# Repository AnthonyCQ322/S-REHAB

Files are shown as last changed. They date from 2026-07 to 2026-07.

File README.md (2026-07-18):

<div align="center">

# S-REHAB




</div>

**Curso:** Instrumentación Biiomédica 

**Proyecto:** sistema wearable modular e inalámbrico creado para monitorear objetivamente la rehabilitación del hombro en pacientes con Síndrome de Pinzamiento Subacromial. 

---

## Sobre el Proyecto

Este repositorio está destinado a registrar el desarrollo de nuestro proyecto académico, es un sistema wearable médico, inalámbrico y de bajo costo diseñado para monitorizar de manera cuantitativa y objetiva la rehabilitación de pacientes jóvenes con Síndrome de Pinzamiento Subacromial. Cuenta con un módulo en el brazo que evalúa la cinemática del movimiento (ROM) con un sensor inercial (BNO055) y la fatiga del trapecio superior mediante sEMG (Myoware), junto con un módulo en el pecho que registra la frecuencia cardíaca mediante el sensor ECG (Max30001) del HealthyPi 5. El  proyecto utiliza Edge Computing que procesa la información localmente para activar un sistema de luces LED que alerta al paciente en tiempo real sobre los movimientos compensatorios o sobreesfuerzo. Finalmente, los datos se transmiten por Bluetooth a una interfaz en Unity 3D y a una plataforma web, ayudando al fisioterapeuta en las evaluaciones subjetivas tradicionales por un análisis clínico basado en datos precisos.

<p align="center">
  Imagen descriptiva del curso
</p>

---

## Integrantes (Grupo 4 S-REHAB)

<table align="center">
  <tr>
    <td align="center" width="33%">
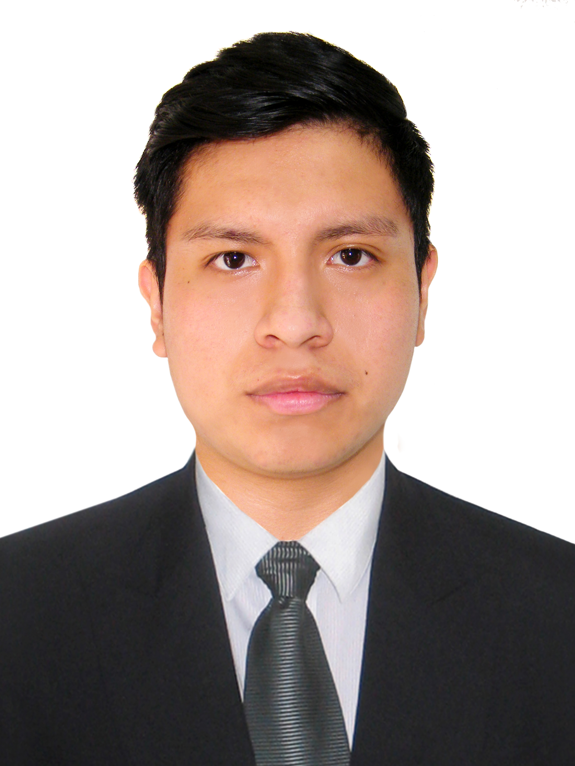
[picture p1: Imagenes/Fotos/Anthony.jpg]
Foto Integrante 1
      <br>
      <b>Anthony Frank Callupe Quispe</b><br>
      <i>"Estudiante de Ingeniería Biomédica apasionado por el análisis de datos médicos."</i><br><br>
      ✉️ <a href="anthony.callupe@upch.pe">anthony.callupe@upch.pe</a>
    </td>
    <td align="center" width="33%">
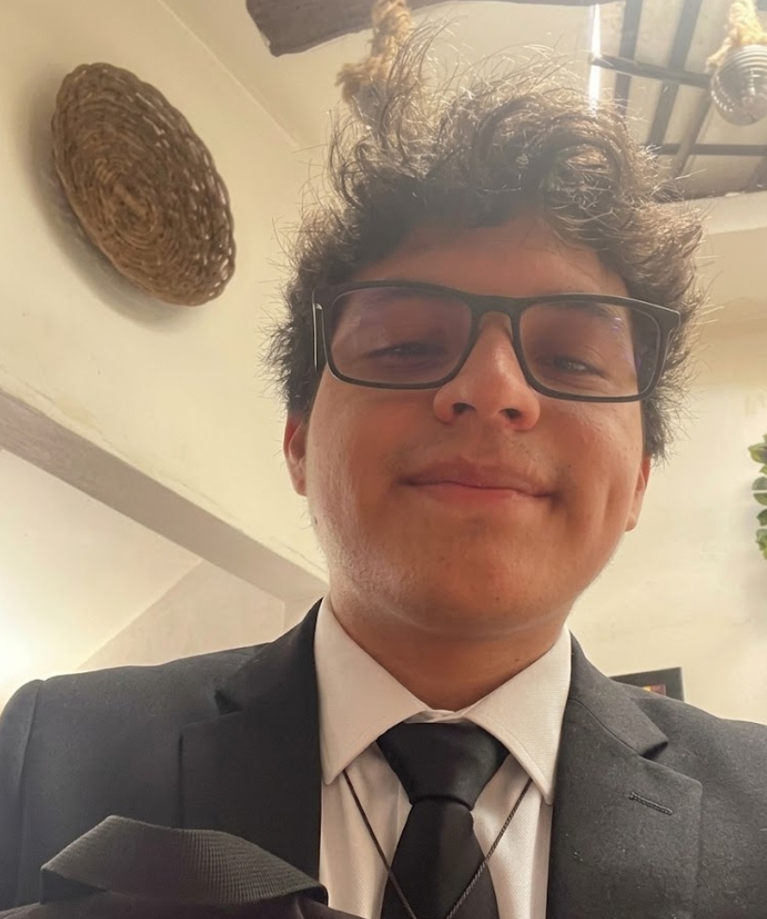
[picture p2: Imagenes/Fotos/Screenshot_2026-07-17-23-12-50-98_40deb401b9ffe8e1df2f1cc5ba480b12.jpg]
Foto Integrante 1
      <br>
      <b>André Vallejo Canchanya</b><br>
      <i>"Apasionado por el Machine Learning y el diagnóstico temprano de enfermedades."</i><br><br>
      ✉️ <a href="andre.vallejo@upch.pe">andre.vallejo@upch.pe</a>
    </td>
    <td align="center" width="33%">
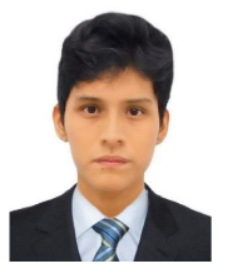
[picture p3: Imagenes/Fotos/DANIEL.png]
Foto Integrante 1
      <br>
      <b>Daniel Bagkdan Cárdenas Paniagua</b><br>
      <i>"Interesada en el procesamiento digital de bioseñales y la programación."</i><br><br>
      ✉️ <a href="daniel.cardenas@upch.pe">daniel.cardenas@upch.pe</a>
    </td>
  </tr>
  <tr>
    <td align="center" width="33%">
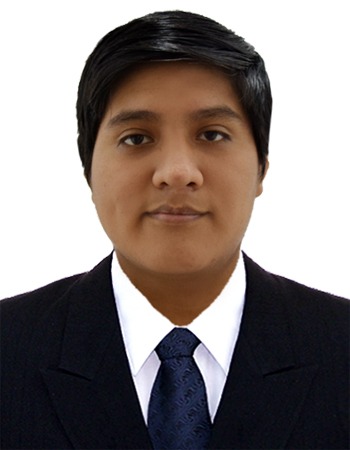
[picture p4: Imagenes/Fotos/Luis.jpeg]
Foto Integrante 1
      <br>
      <b>Luis Alejandro Luque Prado</b><br>
      <i>"Enfocado en el diseño de hardware médico e instrumentación electrónica."</i><br><br>
      ✉️ <a href="luis.luque@upch.pe">luis.luque@upch.pe</a>
    </td>
    <td align="center" width="33%">
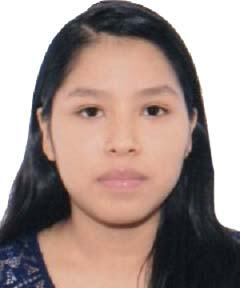
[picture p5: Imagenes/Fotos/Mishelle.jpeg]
Foto Integrante 1
      <br>
      <b>Mishelle Eloisa Llanos Guerrero</b><br>
      <i>"Dedicada a la investigación clínica y la validación de tecnologías de salud."</i><br><br>
      ✉️ <a href="mishelle.llanos@upch.pe">mishelle.llanos@upch.pe</a>
    </td>
    <td align="center" width="33%">
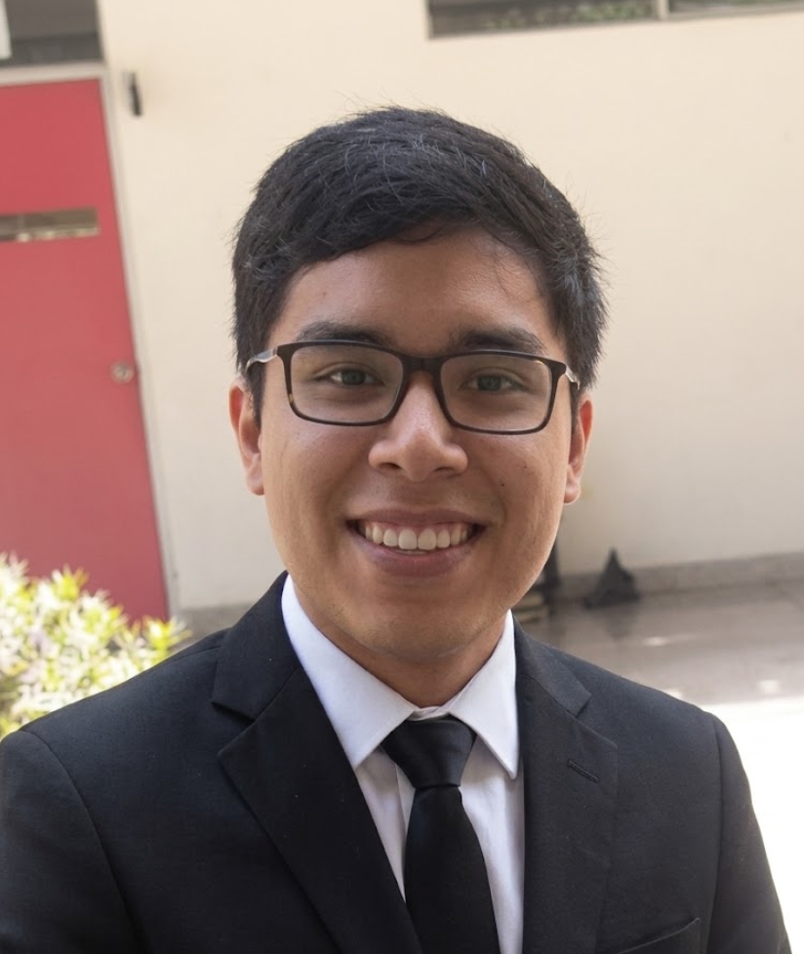
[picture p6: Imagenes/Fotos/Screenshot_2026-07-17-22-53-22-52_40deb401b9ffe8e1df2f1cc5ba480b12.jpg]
Foto Integrante 1
      <br>
      <b>André Alexis Palomino Mozo</b><br>
      <i>"Enfocado en el diseño de hardware médico e instrumentación electrónica."</i><br><br>
      ✉️ <a href="andre.palominoupch.pe">andre.palomino@upch.pe</a>
      </td>
  </tr>
</table>

---

## Docentes del Curso

El desarrollo de este proyecto y el aprendizaje a lo largo del semestre está guiado por nuestros docentes:

*  **HOYOS ALVITEZ MIGUEL ROGGER**

---

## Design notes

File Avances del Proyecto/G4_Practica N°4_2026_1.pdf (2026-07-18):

## UNIVERSIDAD PERUANA CAYETANO HEREDIA INGENIERÍA BIOMÉDICA

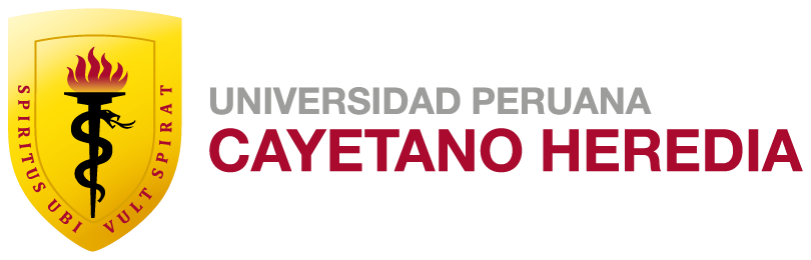
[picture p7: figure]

# PRÁCTICA DE INSTRUMENTACIÓN BIOMÉDICA

Solución final y componentes del prototipo.

# [Práctica N°4]

### GRUPO N° 4

### - Vallejo Canchanya, André - Luque Prado, Luis Alejandro - Cárdenas Paniagua ,Daniel Bagkdan - Callupe Quispe, Anthony Frank - Llanos Guerrero, Mishelle - Palomino Mozo, André Alexis

2026 -1

# Monitoreo Fisiológico y de Movimiento en rehabilitación de miembro superior

## 1. Objetivo

Consolidar la solución seleccionada en la Práctica 3 en una propuesta técnica final coherente e implementable, definiendo los componentes principales del prototipo basado en Healthy Pi 5, su arquitectura de integración, el flujo de uso real del sistema y las consideraciones básicas de usabilidad, seguridad y viabilidad para la siguiente etapa de desarrollo electrónico.

## 2. Integración final de resultados

### 2.1. Problema clínico-tecnológico reformulado

En la población de adultos jóvenes físicamente activos, el dolor de hombro presenta una alta prevalencia, siendo el Síndrome de Pinzamiento Subacromial (SIS) uno de los diagnósticos clínicos más frecuentes, representando hasta dos tercios de los casos de dolor de hombro [1]. En los procesos de rehabilitación actuales, no existe una forma objetiva y cuantitativa de monitorear la ejecución del movimiento. Esto genera una fuerte dependencia de evaluaciones clínicas subjetivas basadas en la observación visual y la estimación manual del fisioterapeuta [2].

Además, la falta de dispositivos accesibles limita la capacidad de cuantificar en tiempo real alteraciones del control escapulohumeral, como la disquinesia escapular y los patrones de activación muscular ineficientes [3]. Como consecuencia, la persistencia de estas compensaciones motoras puede reducir el espacio subacromial y contribuir a la perpetuación del dolor y la disfunción del hombro, afectando negativamente la recuperación funcional del manguito rotador [4].

En este contexto, se evidencia la necesidad de desarrollar herramientas accesibles que permitan un monitoreo objetivo y cuantitativo del control escapulohumeral durante la rehabilitación, facilitando la detección temprana de compensaciones motoras y la optimización de la técnica terapéutica.

### 2.2. Usuario objetivo

El sistema está dirigido a adultos jóvenes (18 a 30 años) con un perfil físicamente activo (deportistas recreativos o usuarios de entrenamiento de fuerza) que presentan diagnóstico de Síndrome de Pinzamiento Subacromial (SIS).

### 2.3. Contexto de uso

El dispositivo será utilizado en entornos intrahospitalarios, centros de terapia física o sesiones domiciliarias , bajo la supervisión de un fisioterapeuta encargado del proceso de rehabilitación.

### 2.4. Variable(s) fisiológica(s) seleccionada(s)

Primarias:

- Cinemática (vía IMU): Rango de movimiento (ROM), aceleración lineal y velocidad angular del miembro superior [5].

- Actividad Eléctrica Muscular Local (vía sEMG): Nivel de reclutamiento de unidades motoras (amplitud) y fatiga espectral (frecuencia mediana) de la musculatura del hombro [6].

Secundarias:

- Actividad Eléctrica del Corazón (ECG): Frecuencia Cardíaca (FC) [7].

### 2.5. Ruta técnica elegida

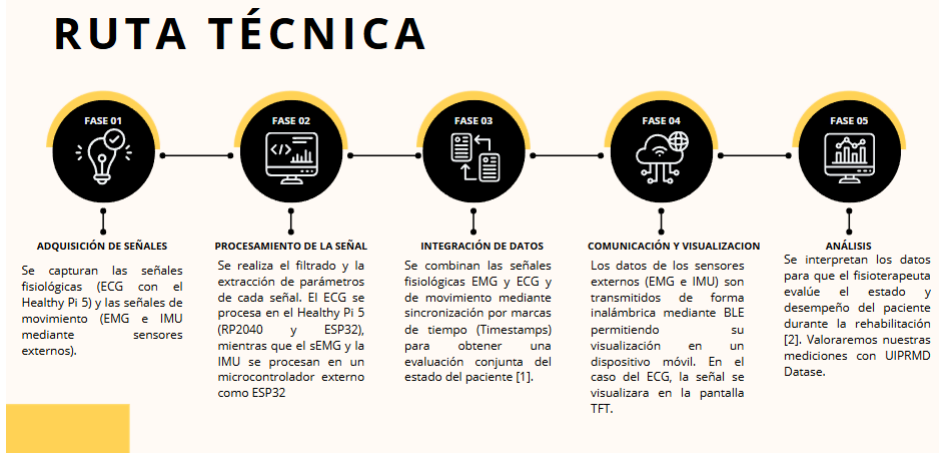
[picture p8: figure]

Fig. 1. Fases de la ruta técnica del sistema.

### 2.6. Solución escogida en la Práctica 3

La solución propuesta consiste en un sistema biomédico wearable, portátil e integrado para el monitoreo simultáneo de variables fisiológicas y cinemáticas durante la rehabilitación del miembro superior. El sistema adopta una arquitectura distribuida de dos módulos:

- Un módulo torácico basado en la plataforma Healthy Pi v5 para la adquisición de la señal ECG.
- Un módulo en el brazo basado en un microcontrolador ESP32 para la captura de señales locales de movimiento (IMU) y actividad muscular (sEMG).

Esta distribución permite desacoplar la adquisición de señales globales y locales, optimizando el procesamiento de datos y mejorando la ergonomía del sistema. La selección tecnológica responde a criterios de viabilidad económica, portabilidad y seguridad, priorizando una solución no invasiva que permite detectar compensaciones motoras sin restringir la movilidad del paciente durante la rehabilitación.

## 3. Solución final propuesta

### 3.1. Objetivo del sistema

Desarrollar un sistema biomédico wearable para el monitoreo en tiempo real durante la rehabilitación del miembro superior, enfocado en la detección de compensaciones motoras y el análisis del nivel de activación muscular, con el fin de mejorar la calidad de ejecución del ejercicio y apoyar la toma de decisiones clínicas.

### 3.2. Función principal

El sistema adquiere, procesa y analiza señales de movimiento (IMU) y actividad muscular (sEMG) para identificar:
- Compensaciones motoras: movimientos incorrectos o patrones de ejecución inadecuados durante el ejercicio.
- Nivel de activación muscular: como indicador del esfuerzo realizado y posible aparición de fatiga de manera indirecta.

Adicionalmente, el sistema registra la señal ECG y la frecuencia cardíaca (FC) como indicador fisiológico complementario.

### 3.3. Usuario final

- Usuario operante: Fisioterapeuta.
- Usuario paciente: Paciente en rehabilitación de miembro superior.

### 3.4. Contexto de uso real

El sistema está orientado a pacientes con disfunciones musculoesqueléticas del hombro en fase de rehabilitación funcional, particularmente aquellos con Síndrome de Pinzamiento Subacromial (SIS). Se utiliza en clínicas de rehabilitación o en sesiones domiciliarias supervisadas, donde el paciente ejecuta ejercicios terapéuticos mientras el fisioterapeuta monitorea la calidad del movimiento, la activación muscular y la evolución del desempeño.

### 3.5. Salida principal del sistema (visualización, alerta, registro o reporte)

### 3.5.1. Visualización en tiempo real

### 1. Visualización

- Indicador de calidad de movimiento (correcto / compensado), mostrado mediante la aplicación móvil.
- Nivel de activación muscular, representado mediante gráficos simples en función del tiempo.

### 2. Alertas de ejecución

- Notificación de compensaciones motoras para corrección de técnica.
- Indicación de niveles elevados y sostenidos de activación muscular que sugieren posible fatiga.

### 3. Registro de datos

- Señales de movimiento (IMU), sEMG y ECG almacenadas para análisis posterior.

### 4. Estado del sistema

- Indicadores LED que comunican el estado del dispositivo y la ejecución del movimiento de forma simple e intuitiva.

### 3.6. Valor agregado de la propuesta frente a las soluciones revisadas anteriormente

- Integración multimodal: combina análisis de movimiento (IMU) y actividad muscular (sEMG), permitiendo una evaluación más completa de la ejecución del ejercicio.

- Arquitectura distribuida sincronizada: el sistema opera mediante dos módulos independientes (brazo y pecho), cuya información es integrada en la aplicación móvil mediante sincronización por marcas de tiempo (timestamps), permitiendo correlacionar eventos de movimiento y activación muscular.
- Priorización del procesamiento: las variables críticas para la terapia (movimiento y activación muscular) se procesan en tiempo real, mientras que el análisis más complejo (como tendencias de fatiga) se realiza de forma diferida, mejorando la viabilidad del sistema y evitando la sobrecarga de información.

## 4. Componentes principales del prototipo

Módulo / Componente | Marca / Módulo | Función dentro del sistema | Variable o señal asociada | Característica técnica principal | Razón de selección
Plataforma base Healthy Pi 5 | ProtoCentra l (HealthyPi 5) | Procesamiento central de ECG y referencia temporal del sistema | Señal ECG, FC | Integra AFE clínico (MAX30001), microcontrolad or RP2040 y módulo inalámbrico ESP32-C3. | Centraliza la adquisición de la señal cardíaca, simplifica la integración del sistema y permite procesamiento local en tiempo real.
Sensor ECG | MAX30001 (Integrado en HealthyPi v5) | Adquisición y acondicionamient o de señales eléctricas cardíacas. | Señal ECG | AFE (Analog Front-End) de canal único, alta relación señal-ruido, protección contra desfibrilación. | Permite la adquisición de señal ECG con calidad adecuada para el monitoreo de la frecuencia cardíaca en tiempo real, sin requerir etapas adicionales de acondicionamiento analógico.

Sensor EMG | MyoWare Muscle Sensor (o módulo sEMG) | Monitoreo de nivel de activación muscular (indicador indirecto de fatiga | Señal EMG | Ancho de banda específico para músculos, salida analógica de envolvente (rectificada e integrada) o cruda. | Corrige el error del AD8232. Está diseñado específicamente para el espectro de frecuencias musculares, garantizando datos válidos.
Sensor IMU | BNO055 | Estimación de orientación del segmento corporal y cálculo de ángulos relativos | Ángulos de Euler, Cuaterniones y Gravedad lineal. | Sensor de 9 DoF con Digital Motion Processor (DMP) integrado para fusión de datos. | Entrega directamente datos de orientación procesados por hardware, reduciendo la necesidad de implementar algoritmos complejos de fusión (p. ej., filtros de Kalman) en el microcontrolador y facilitando la detección de patrones de movimiento en tiempo real.
Microcontrolad or secundario | ESP32 DevKit V1 | Digitalización de señales locales y transmisión inalámbrica de datos. | sEMG digitalizada y datos cinemáticos | Wi-Fi y Bluetooth Low Energy (BLE) integrados, ADC de 12 bits, doble núcleo. | Permite la arquitectura distribuida. Procesa y envía datos localmente en el brazo, evitando cables largos hacia el pecho.
Pantalla TFT (local) | TFT 3.5” (ST7797 o ILI9488) | Visualización en tiempo real de la estabilidad fisiológica sistémica. | Visualización de ECG y FC (BPM) | 3.5", resolución nativa, navegación por interruptor lateral. | Permite monitorear el esfuerzo cardíaco del paciente de forma directa sin dispositivos externos.

Módulo de visualización | Smartphone (App móvil) | Análisis biomecánico detallado y monitoreo de la técnica de rehabilitación. | Señal sEMG, Ángulos IMU, Trayectorias. | Interfaz gráfica avanzada con registro histórico vía BLE. | Facilita al especialista la evaluación de la compensación motora y fatiga sin saturar la pantalla pequeña del torso.
Sistema de alimentación | Batería Li-Po) + Módulo TP4056 | Gestión y suministro de energía autónoma regulada. | Voltaje DC (V) | Recargable, portátil y eficiente. | Garantiza la portabilidad (wearable) y cumple con el principio de seguridad eléctrica (aislado de la red comercial).
Módulo de comunicación | ESP32C3 RISC-V | Enlace inalámbrico (BLE) entre nodos y dispositivos receptor. | Paquetes de datos digitales (BLE) | Protocolo Bluetooth Low Energy 4.2 o 5.0. | Minimiza el consumo de batería, elimina el riesgo de enredo de cables y ofrece ancho de banda suficiente.
Electrodos | 3M Red Dot (Ag/AgCl) para sEMG y ECG. Pre-gelificad os, de baja impedancia | Transducción de potenciales bioeléctricos de la piel al sistema. | Potenciales bioeléctricos (mV) | Gel conductor sólido, desechables, alta adhesión, estándar ISO 10993. | Garantizan baja impedancia, reducen artefactos por movimiento y aseguran la higiene entre distintos pacientes.
Actuadores | Indicadores LED (verde/amari llo/rojo) | Generación de retroalimentación inmediata sobre la técnica de ejecución. | Señal digital | Bajo consumo (3V – 5V) y alta visibilidad | Permite diferenciar claramente entre estado del sistema y feedback de ejecución sin generar confusión clínica: verde indica funcionamiento correcto o ejecución adecuada, amarillo señala compensación motora (requiere corrección), y azul

nivel de activación
sostenida | que
sugiere | posible
fatiga

Tabla 1. Componentes del prototipo. Resumen de los módulos principales del sistema, sus funciones, variables asociadas y criterios técnicos de selección.

4. 1. Justificación técnica más detallada

### 4.1.1. AFE Bioeléctrico: MAX30001 (Integrado en HealthyPi v5)

El MAX30001 es un front-end analógico de biopotenciales diseñado para aplicaciones médicas portátiles, optimizado para la adquisición de señales ECG con calidad clínica y bajo consumo energético. Estudios comparativos muestran que la frecuencia cardíaca obtenida a partir de señales indirectas (como acelerómetros) presenta alta correlación (>0.99) con ECG clínico, confirmando que el ECG sigue siendo el estándar de referencia para mediciones cardiovasculares [8]. En este contexto, el uso del MAX30001, diseñado para ECG de grado clínico, garantiza una medición precisa y confiable de FC, validando su aplicación en monitoreo wearable sin comprometer la calidad diagnóstica.

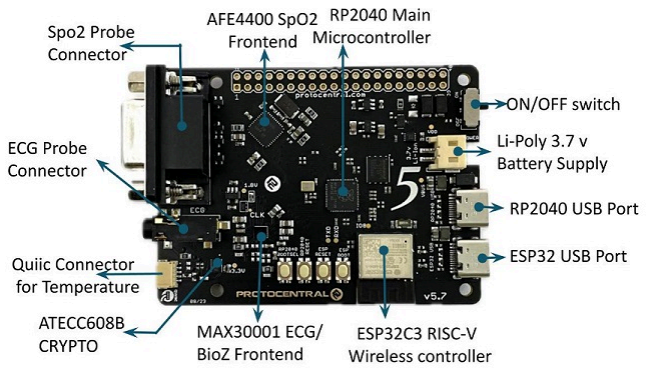
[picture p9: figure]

Fig. 2. Módulo AFE bioeléctrico basado en el MAX30001 integrado en la plataforma Healthy Pi 5.

Documentación técnica: Front/End analógico (AFE) biopotencial y bioimpedancia MAX30001 (https://www.digikey.es/es/product-highlight/m/maxim-integrated/max30001-biopotential-and-bioimpedance-afe)

- Rango de medición: ECG hasta ~65 mVpp con tolerancia a offsets de ±650 mV. Evita saturación por movimiento o contacto deficiente
- Resolución: ADC de 18 bits que permite detectar variaciones finas en la señal.
- Tipo de señal: Señal bioeléctrica de baja amplitud con alta impedancia (>1 GΩ) y alto CMRR.
- Voltaje o alimentación: Opera entre 1.8V–3.3V con consumo bajo (~0.5 mA).
- Interfaz de comunicación: SPI
- Portabilidad: Diseñado para wearables con modos de bajo consumo y FIFO interno.
- Compatibilidad con Healthy Pi 5: Integrado directamente en la plataforma. Elimina la necesidad de diseño analógico externo.
- Facilidad de implementación: Repositorio libre en GitHub y librerías disponibles en Protocentral Healthy Pi 5.
- Disponibilidad o costo aproximado: Costo aproximado de 10–16 € por chip

### 4.1.2. Sensor sEMG: MyoWare Muscle Sensor

El sensor MyoWare 2.0 permite la adquisición de señales electromiográficas superficiales (sEMG), utilizadas clínicamente para analizar la activación muscular y la coordinación motora. La electromiografía es una técnica ampliamente validada para evaluar patrones de contracción y fatiga muscular, proporcionando información sobre la intensidad y temporización del reclutamiento muscular en tiempo real [9]. En este contexto, el uso del MyoWare permite integrar mediciones musculares funcionales en un sistema wearable, complementando el análisis fisiológico con información biomecánica relevante para la rehabilitación de miembros superiores.

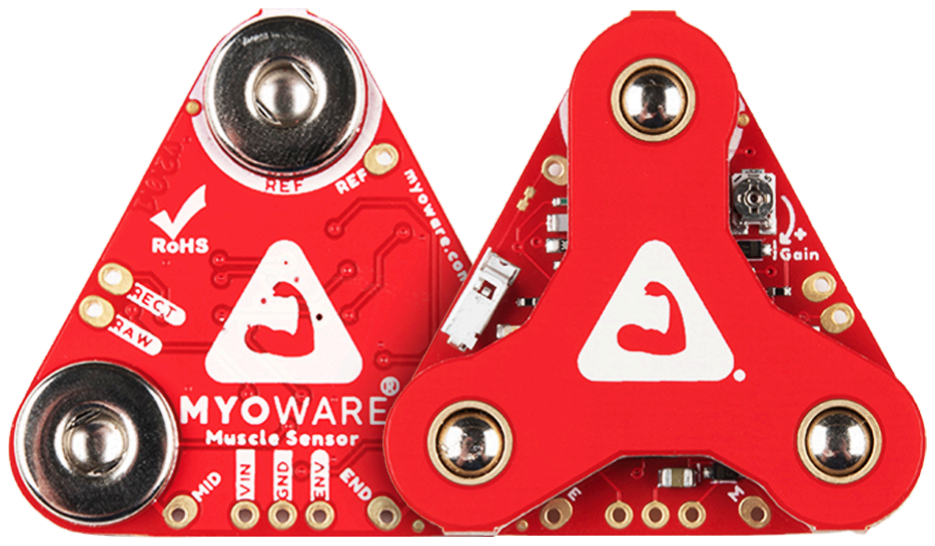
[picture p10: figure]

Fig. 3. Sensor de electromiografía superficial MyoWare 2.0 Muscle Sensor empleado para la medición de la actividad muscular (sEMG).

Especificaciones tecnica: Sensor EMG MyoWare 2.0, (https://naylampmechatronics.com/biomedico/1263-sensor-emg-myoware-20.html) otra versión (MyoWare™ (https://cdn.sparkfun.com/datasheets/Sensors/Biometric/MyowareUserManualAT-04-001.pdf) )

- Rango de medición: Señales EMG de baja amplitud (≈0–10 mV) amplificadas con ganancia ≈200. Salida adaptada a 0–Vcc para fácil adquisición.
- Resolución: Dependiente del ADC (ej. 12 bits en ESP32), suficiente para diferenciar niveles de activación muscular.
- Tipo de señal: Señal analógica con salidas RAW, rectificada y envolvente. Permite análisis en tiempo real sin procesamiento complejo.
- Voltaje o alimentación: Opera entre 2.27V–5.47V (típico 3.3V–5V). Compatible con sistemas embebidos portátiles.
- Interfaz de comunicación: Salida analógica directa hacia ADC. No requiere protocolos digitales adicionales.
- Portabilidad: Diseño compacto con sistema snap y electrodos integrados. Reduce cableado y facilita uso wearable.
- Compatibilidad con Healthy Pi 5: Requiere adquisición mediante microcontrolador externo (ESP32). Se integra vía arquitectura distribuida.
- Facilidad de implementación: Incluye filtrado (20–500 Hz), rectificación y ganancia ajustable. Evita diseñar acondicionamiento analógico.
- Disponibilidad o costo aproximado: Costo aproximado de S/ 370 en Perú. Disponible en proveedores locales.

### 3. Unidad de Medición Inercial (IMU): BNO055

El BNO055 es un sensor inercial de 9 grados de libertad ampliamente utilizado en aplicaciones biomédicas y de movimiento para estimar orientación corporal. La medición de aceleración, velocidad angular y campo magnético permite caracterizar la cinemática del movimiento humano, siendo clave en análisis biomecánico y rehabilitación [10]. Su integración de fusión de sensores en hardware permite obtener directamente orientación absoluta, facilitando el monitoreo preciso de la técnica del paciente en entornos wearables.

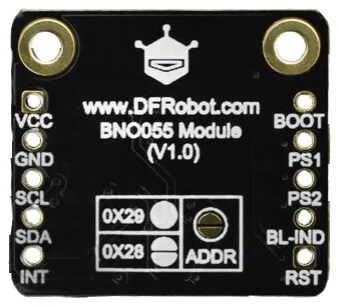
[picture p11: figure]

Fig. 4. Unidad de medición inercial BNO055 utilizada para la estimación de orientación y movimiento corporal mediante fusión de sensores.

Descripción técnica: BNO055 (https://mtlab.pe/producto/bno055-modulo-sensor-de-9-ejes-fermion-dfrobot/)

- Rango de medición: Acelerómetro ±2–16g, giroscopio ±125–2000 °/s, magnetómetro hasta ±1300 µT. Permite capturar movimientos humanos completos.
- Resolución: Acelerómetro de 14 bits y giroscopio de 16 bits. Proporciona alta precisión en la estimación de movimiento.
- Tipo de señal: Datos digitales procesados (cuaterniones, ángulos de Euler). Reduce la necesidad de procesamiento externo.
- Voltaje o alimentación: Opera entre 3.3V–5.5V. Compatible con sistemas embebidos portátiles.
- Interfaz de comunicación: I2C (principal) o SPI. Facilita integración con microcontroladores.
- Portabilidad: Tamaño compacto (~19x21 mm) y bajo consumo. Adecuado para dispositivos wearables.
- Compatibilidad con Healthy Pi 5: Integrable mediante I2C con MCU auxiliar (ESP32). Compatible con arquitectura distribuida.
- Facilidad de implementación: Incluye microcontrolador interno para sensor fusion. Elimina necesidad de filtros complejos (ej. Kalman).
- Disponibilidad o costo aproximado: Costo aproximado de $17–18 USD. Disponible en múltiples proveedores.

## 5. Diagrama de integración del sistema

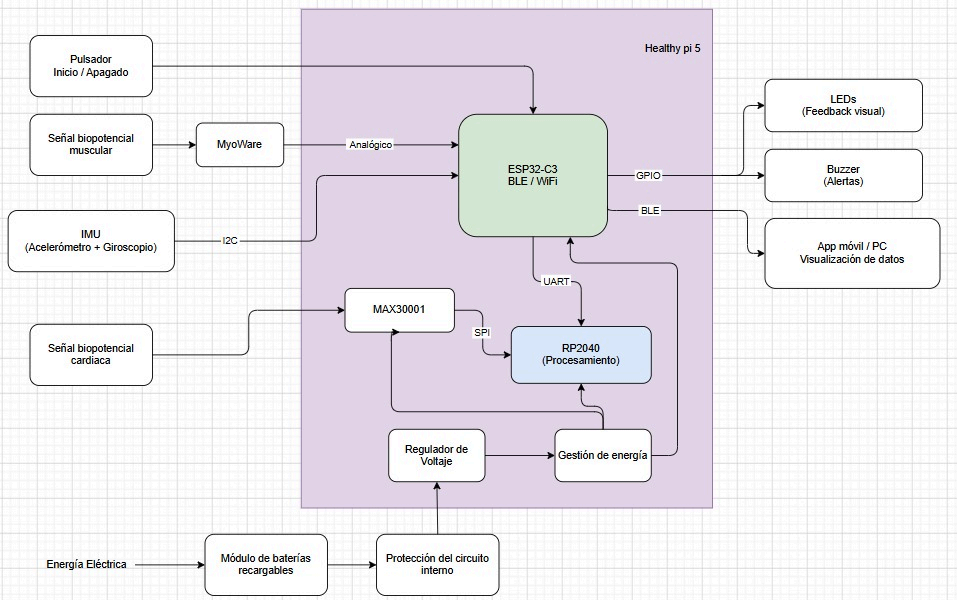
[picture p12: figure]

Fig. 5. Diagrama de bloques

## 6. Priorización de implementación

Elemento | Estado de Adquisición | Clasificación | Justificación
Healthy Pi 5 | Cubierto por el curso | Indispensable | Centraliza el procesamiento de ECG, gestión temporal y comunicación central.
Sensor ECG (Max30001) | Cubierto por el Healthy Pi 5 | Indispensable | Obtiene la frecuencia cardíaca (FC) de grado clínico.
Esp32 DevKit V1 | Integrar | Indispensable | Microcontrolador secundario necesario para el control del sensor IMU y el sensor sEMG en el brazo.
Sensor IMU (BNO055) | Adquirir | Indispensable | Variable primaria que entrega ángulos y velocidades procesados por hardware para detectar las compensaciones de movimiento.
Sensor sEMG (MyoWare) | Adquirir | Indispensable | Variable primaria que permite monitorear el nivel de activación y fatiga muscular.
Baterías Li-Po (3.7V) | Adquirir | Indispensable | Garantiza la seguridad eléctrica al estar aislada de la red eléctrica y la portabilidad.

Electrodos Ag/AgCl | Adquirir | Indispensable | Interfaz para la transducción de potenciales bioeléctricos.
Pantalla TFT 3.5" | Cubierto por el Healthy Pi 5 | Recomendable | Mostrará la monitorización del estado del sistema y FC de forma directa.
Indicadores LED | Adquirir | Recomendable | Brinda retroalimentación al paciente sobre la calidad técnica del movimiento.
Aplicativo | Referencial | Recomendable | Permite la visualización avanzada de gráficas y registro de datos del movimiento por el IMU.
Bandas elásticas y Case | Montaje | Opcional | Mejora la ergonomía y fijación.

Tabla 2. Elementos Indispensables, Recomendables y Opcionales para la elaboración del dispositivo final.

## 7. Escenario de uso real y tareas críticas

- Quién lo usa: Adultos jóvenes de 18 a 30 años físicamente activos con diagnóstico de Síndrome de Pinzamiento Subacromial donde el fisioterapeuta supervisa las sesiones.
- Dónde lo usa: Entornos intrahospitalarios, centros de terapia física.
- Cómo se coloca o inicia: El fisioterapeuta coloca el dispositivo al paciente, los electrodos sEMG se ubican en el trapecio superior y los de ECG en el tórax. El dispositivo se inicia mediante una conexión Bluetooth enviando información de los sensores hacia la app.
- Qué información observa o recibe:
- El paciente recibe retroalimentación mediante LEDs donde el color verde indica ejecución correcta, amarillo indica compensación motora y el Azul indica posible fatiga.
- El fisioterapeuta observa en la pantalla TFT la frecuencia cardíaca y la señal ECG mientras que en la app móvil visualiza las señales de EMG, ECG y la calidad de movimiento.
- Qué acción se espera del usuario o cuidador: El paciente debe realizar los movimientos indicados mientras que el fisioterapeuta analiza los datos y realiza correcciones de técnica gracias a la información obtenida.
- Cómo termina o se retira el sistema: Finalizando la sesión el fisioterapeuta retira el dispositivo del paciente y se desechan los electrodos Ag/AgCl para una correcta higiene.
Tarea crítica | Posible error de uso | Consecuencia o riesgo | Medida de diseño para mitigarlo
Colocación de electrodos sEMG | Ubicación fuera de la zona activa entre C7 y el acromion. | Baja calidad de la señal, captación de ruido. | Uso de cables tipo snap de longitud reducida con ruta anatómica fija para evitar tracciones.
Sincronización de módulos inalámbricos | Falla en una de las dos conexiones BLE simultáneas con la app. | Desfase temporal entre los datos de movimiento del IMU y la actividad muscular EMG. | La app centraliza la sincronización mediante el uso de timestamps para ambas señales.

Gestión de
alimentación de la
batería.

Uso del dispositivo
con un nivel de carga
insuficiente en alguno
de los módulos.

Apagado del sistema
y pérdida de
monitoreo durante la
sesión.

Uso de un LED de
estado del sistema para
confirmar el encendido
y funcionamiento
correcto.

Tabla 3. Tareas críticas y sus posibles errores y consecuencias del dispositivo

## 8. Consideraciones de usabilidad, seguridad y restricciones

El diseño del sistema wearable consideramos criterios de seguridad eléctrica, biocompatibilidad, ergonomía y usabilidad, los cuales condicionan directamente la arquitectura del sistema y las decisiones de diseño, con el fin de garantizar una medición confiable sin interferir con el patrón motor del paciente.

### 8.1. Normas y guías relevantes

El desarrollo del sistema se fundamenta en estándares internacionales que aseguran su seguridad y validez técnica:

- IEC 60601-1: Medical Electrical Equipment, General Requirements for Basic Safety and Essential Performance [11].
Establece los requisitos de seguridad eléctrica para equipos médicos. Su aplicación es crítica debido al uso simultáneo de dos módulos electrónicos con electrodos en contacto con el paciente, regulando las corrientes de fuga en partes aplicadas tipo BF y condicionando la necesidad de aislamiento entre nodos .
- ISO 10993-1: Biological Evaluation of Medical Devices [12].
Define los lineamientos para la evaluación de biocompatibilidad de materiales en contacto con el cuerpo humano. Se aplica a los electrodos adhesivos tipo Ag/AgCl utilizados en ECG y sEMG, garantizando seguridad en contacto cutáneo.
- SENIAM: Surface Electromyography for the Non-Invasive Assessment of Muscles Proporciona recomendaciones para la colocación de electrodos sEMG. Para el trapecio superior, establece la ubicación de los electrodos activos entre C7 y el acromion, con separación aproximada de 20 mm y orientación paralela a las fibras musculares, y el electrodo de referencia en el acromion. Su aplicación asegura la reproducibilidad y calidad de la señal [13].

### 8.2. Restricciones de diseño derivadas del contexto de uso

- Seguridad eléctrica en presencia de múltiples puntos de contacto: El sistema utiliza dos módulos independientes (pecho y brazo), cada uno con electrodos conectados al paciente. Esto introduce la necesidad de evitar trayectorias de corriente entre nodos y garantizar aislamiento eléctrico durante la operación.
- No interferencia con el movimiento del hombro: El dispositivo se emplea durante ejercicios activos de rehabilitación, por lo que no debe restringir el rango de movimiento ni alterar el patrón motor, ya que esto afectaría directamente la validez de las mediciones cinemáticas y musculares.
- Sensibilidad de la señal EMG al movimiento: La señal sEMG es susceptible a artefactos por movimiento y variaciones en la impedancia de contacto, lo que exige estabilidad en la colocación de electrodos y control del cableado.

- Gestión de la información según el usuario: El sistema genera múltiples variables fisiológicas, por lo que se requiere evitar la sobrecarga de información durante la sesión, diferenciando la información mostrada al fisioterapeuta y al paciente.

### 8.4. Decisiones de diseño adoptadas

- Arquitectura distribuida con comunicación inalámbrica (BLE): Cada módulo (Módulo Principal: Healthy pi y Módulo Secundario: ESP32+IMU+Myoware) opera de manera independiente y transmite datos mediante Bluetooth Low Energy (BLE) hacia una aplicación central. Esto permite eliminar conexiones físicas entre módulos durante el uso, reduciendo riesgos eléctricos y mejorando la libertad de movimiento.
- Alimentación autónoma mediante baterías Li-Po: Cada módulo cuenta con una batería Li-Po de 3.7V permitiendo la operación aislada de la red eléctrica. La recarga se realiza fuera del contacto con el paciente, reduciendo riesgos conforme a IEC 60601-1.
- Colocación estandarizada de electrodos: Los electrodos sEMG se ubican en el trapecio superior siguiendo SENIAM, con el electrodo de referencia en el acromion para mejorar estabilidad mecánica y reducir ruido. Los electrodos ECG se colocan en el tórax según configuración estándar. En ambos casos se emplean electrodos Ag/AgCl desechables para asegurar biocompatibilidad y baja impedancia.
- Minimización y fijación del cableado: Se emplearán cables tipo snap de longitud reducida, fijados al cuerpo mediante material adhesivo y enrutados por la región superior del hombro hacia el módulo del brazo. El cableado se dispone adherido a la piel, siguiendo trayectorias anatómicas que minimizan el movimiento relativo, evitando tracción sobre los electrodos y reduciendo artefactos durante la ejecución de los ejercicios.
- Ubicación proximal de los módulos: El módulo del brazo (ESP32 + IMU + sEMG) se ubica en la región deltoidea, reduciendo la longitud del cableado y favoreciendo la integración con el movimiento. El módulo de ECG se fija en el pecho para minimizar la distancia con los electrodos. Ambos módulos se integran en bandas elásticas con bolsillo incorporado, facilitando su colocación, ajuste y limpieza entre sesiones.
- Diseño de interfaz centrado en el usuario: Durante la rehabilitación, el sistema muestra únicamente información crítica en tiempo real, distribuida en dos módulos para evitar la sobrecarga cognitiva.

Módulo principal: El módulo del brazo (ESP32 + IMU + sEMG) brinda retroalimentación mínima mediante:

- LED verde: ejecución correcta del movimiento.
- LED amarillo: detección de compensación motora (requiere corrección).
- LED azul: nivel elevado y sostenido de activación muscular que sugiere posible fatiga y recomienda pausa.

No se presentan métricas ni alertas complejas, para no interferir con la concentración del paciente.

Módulo secundario: El módulo del pecho (Healthy Pi + pantalla TFT) presenta información básica en una interfaz simplificada:

- Frecuencia cardíaca (BPM).
- Señal ECG en tiempo real.

En caso de ejecución incorrecta, el sistema envía una notificación en tiempo real al fisioterapeuta, junto con indicadores de calidad de movimiento y nivel de activación muscular. La aplicación muestra estos datos de forma simple en tiempo real y registra las señales (movimiento, sEMG y ECG) para su análisis posterior. La estimación de fatiga muscular se realiza fuera de la sesión para evitar sobrecarga de información durante la terapia.

## 9. Bibliografía

[1] B. Singh, N. Bakti, y A. Gulihar, “Current concepts in the diagnosis and treatment of shoulder impingement”, Indian J. Orthop., vol. 51, núm. 5, pp. 516–523, 2017.
[2] J. Adolf et al., “Evaluation of functional tests performance using a camera-based and machine learning approach”, PLoS One, vol. 18, núm. 11, p. e0288279, 2023.
[3] U. G. Longo et al., “Scapular Dyskinesis: From basic science to ultimate treatment”, Int. J. Environ. Res. Public Health, vol. 17, núm. 8, p. 2974, 2020.
[4] W. B. Kibler, P. M. Ludewig, P. W. McClure, L. A. Michener, K. Bak, y A. D. Sciascia, “Clinical implications of scapular dyskinesis in shoulder injury: the 2013 consensus statement from the ‘Scapular Summit’”, Br. J. Sports Med., vol. 47, núm. 14, pp. 877–885, 2013.
[5] A. Carnevale et al., “Wearable systems for shoulder kinematics assessment: a systematic review”, BMC Musculoskelet. Disord., vol. 20, núm. 1, p. 546, 2019.
[6] S. B. Rodrigues, L. P. de Faria, A. M. Monteiro, J. L. Lima, T. M. Barbosa, y J. A. Duarte, “EMG signal processing for the study of localized muscle fatigue-pilot study to explore the applicability of a novel method”, Int. J. Environ. Res. Public Health, vol. 19, núm. 20, p. 13270, 2022.
[7] F. Shaffer y J. P. Ginsberg, “An overview of heart rate variability metrics and norms”, Front. Public Health, vol. 5, p. 258, 2017.
[8] Payette, J., Vaussenat, F., & Cloutier, SG (2024). Medición de la frecuencia cardíaca mediante el acelerómetro triaxial integrado en un dispositivo de escritura digital comercial. Sensors , 24 (7), 2238. https://doi.org/10.3390/s24072238
[9] Bu D, Guo S, Li H. sEMG-Based Motion Recognition of Upper Limb Rehabilitation Using the Improved Yolo-v4 Algorithm. Life (Basel). 2022 Jan 3;12(1):64. doi: 10.3390/life12010064. PMID: 35054457; PMCID: PMC8778025.
[10] Fritsche, O., Camacho, S., Hossain, MSB et al. ULTRA-MoCap: Un conjunto de datos multimodales de IMU y sEMG para el análisis cinemático de las articulaciones de la parte superior del cuerpo. Sci Data 13 , 622 (2026). https://doi.org/10.1038/s41597-026-06687-5
[11] | “IEC | 60601-1-11:2015”. | ISO. | [En | línea]. | Disponible:
https://www.iso.org/standard/65529.html
[12] “ISO 10993-1:2025”. ISO. [En línea]. Disponible: https://www.iso.org/standard/10993-1
[13] | “Sensor | Locations”. | Welcome | to | SENIAM. | [En | línea]. | Disponible:
http://seniam.org/trapeziusdescendens.html

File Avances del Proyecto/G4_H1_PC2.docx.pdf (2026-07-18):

## UNIVERSIDAD PERUANA CAYETANO HEREDIA INGENIERÍA BIOMÉDICA

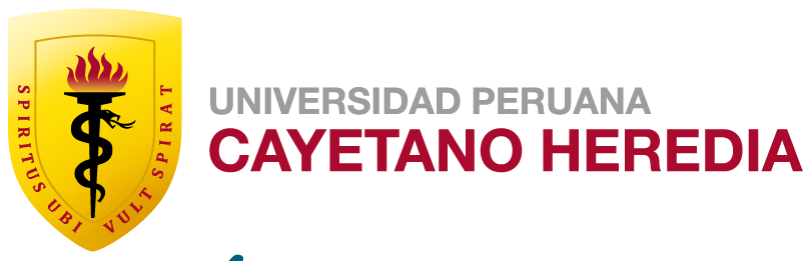
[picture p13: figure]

# PRÁCTICA DE INSTRUMENTACIÓN BIOMÉDICA

# Presentación de la Problemática Tecnológica, desarrollo de la idea de solución, y la lista de exigencias

# [Práctica N°2]

### GRUPO N°4: Nombre de los Integrantes y código: - Vallejo Canchanya, André - 73639949 - Cárdenas Paniagua,Daniel Bagkdan - 75347191 ∙Llanos Guerrero, Mishelle - 70946842 ∙Luque Prado, Luis Alejandro - 79136683 ∙Callupe Quispe Anthony Frank - 72423722 - Palomino Mozo, André Alexis - 74036832

2026

# Monitoreo Fisiológico y de Movimiento en rehabilitación de miembro superior

### I. Reformulación del problema tecnológico

i. Variable fisiológica o biomédica de interés
Se propone utilizar un conjunto de variables fisiológicas que integran tanto la técnica del ejercicio como el nivel de fatiga del paciente.
a. Variable Fisiológica Sistemática
Se planea medir la frecuencia cardiaca mediante señales de electrocardiograma(ECG) para medir la fatiga sistemática del paciente
b. Variable Fisiológica Local
Se planea medir la actividad eléctrica muscular mediante electromiografía de superficie (sEMG) enfocada en los músculos del hombro para medir la fatiga muscular del ejercicio y detectar la correcta activación de los músculos involucrados en las terapias.
c. Variable Cinemática
Se planea medir la aceleración lineal y angular en 3D para calcular el rango de movimiento y trayectoria de los ejercicios.

ii. Método de adquisición propuesto
El sistema utilizará un método de adquisición de montaje superficial (wearable), continuo y no invasivo.
a. Biopotenciales (ECG/sEMG)
Se utilizarán electrodos de superficie las cuales serán colocados estratégicamente en el tórax,abdomen y músculos para trabajar en los ejercicios.
b. Datos Cinemáticos
Se obtendrán a través de Unidades de Medición Inercial (IMUs) que estos integran acelerómetros y giroscopios para transmitir datos de posicionamiento espacial de manera digital.

iii. Contexto de uso
El contexto de uso inicial está delimitado a entornos intrahospitalarios y centros privados de terapia física, la cual se encontrará operando bajo la supervisión directa de un fisioterapeuta durante la rehabilitación. El dispositivo funcionará aislado de la red eléctrica comercial (alimentación por baterías) para garantizar portabilidad y seguridad eléctrica.

iv. Principal brecha tecnológica detectada
Existe una fuerte dependencia de la evaluación clínica subjetiva ya que esta se realiza mediante palpación y observación de expresiones faciales para determinar la fatiga y el progreso terapéutico.Existen soluciones cuantitativas como sistemas como el Kinect o guantes robóticos pero son demasiados costosos o complejas de calibrar.
En contraste el sistema de salud público carece de herramientas wearables de bajo costo que nos permitan evidenciar el estado interno del paciente en tiempo real.
v. Oportunidad concreta de desarrollo
Se propone la integración y sincronización de señales biomecánicas y fisiológicas en un único sistema portátil de low cost.
Este sistema traducirá la señales biológicas complejas en una interfaz con retroalimentación visual clara e intuitiva (alertas de fatiga o mala técnica),lo cual permitirá a los terapeutas a tomar decisiones clínicas más objetivas,adaptar las cargas de trabajo de forma segura y fomentar una mayor adherencia al tratamiento al mostrarle al paciente un progreso cuantificable.

### II. Decisión técnica basada en Healthy Pi 5

i. Señal o señales del Healthy Pi 5

ECG de 1 derivación
La señal de electrocardiografía (ECG) es una señal bioeléctrica que representa la actividad eléctrica del corazón, generada por los procesos de despolarización y repolarización del miocardio. Esta señal puede ser obtenida mediante el Healthy Pi 5, el cual integra el sensor MAX 30001 para capturar señales cardíacas. La medición se realiza mediante tres derivaciones con electrodos desechables, cuya colocación y contacto con la piel permiten obtener un ploteo correcto de la señal. A partir del procesamiento de la señal ECG, es posible extraer la frecuencia cardíaca y la variabilidad de la frecuencia cardíaca (HRV) mediante técnicas de filtrado y la detección de picos R.

ii. ¿La placa base es suficiente o se requieren sensores externos?

No, en el caso de la señal de electromiografía (EMG), esta no se encuentra integrada en la plataforma, por lo que requiere sensores externos. Entre las opciones disponibles, el MyoWare 2.0 ofrece una señal más limpia y fácil de implementar, aunque con mayor costo; el AD8232 es una alternativa más económica pero más susceptible al ruido; y soluciones como OYMotion EMG eliminan el uso de electrodos y reducen interferencias, aunque son más costosas. Por otro lado, para el análisis del movimiento se pueden emplear sensores IMU como el MPU6050 o el MPU9250, que permiten medir aceleración y velocidad angular para estimar la orientación y el movimiento del miembro superior. La elección de estos sensores dependerá del equilibrio entre precisión, costo y facilidad de implementación.

iii. ¿Dónde ocurre el procesamiento principal?

El procesamiento principal del sistema se realiza de forma distribuida. Para las señales fisiológicas como el ECG, el procesamiento se lleva a cabo directamente en la placa Healthy Pi 5, utilizando sus microcontroladores integrados (RP2040 y ESP32), los cuales permiten la adquisición y procesamiento inicial de la señal, incluyendo filtrado y extracción de parámetros como la frecuencia cardíaca. Por otro lado, para sensores externos como EMG e IMU, se puede emplear un microcontrolador adicional como un ESP32 o Arduino Nano, encargado de la adquisición y procesamiento básico de estas señales analógicas. Posteriormente, los datos son transmitidos de forma inalámbrica a un dispositivo móvil por BLE, donde se realiza la visualización en tiempo real.

iv. Ruta técnica del proyecto

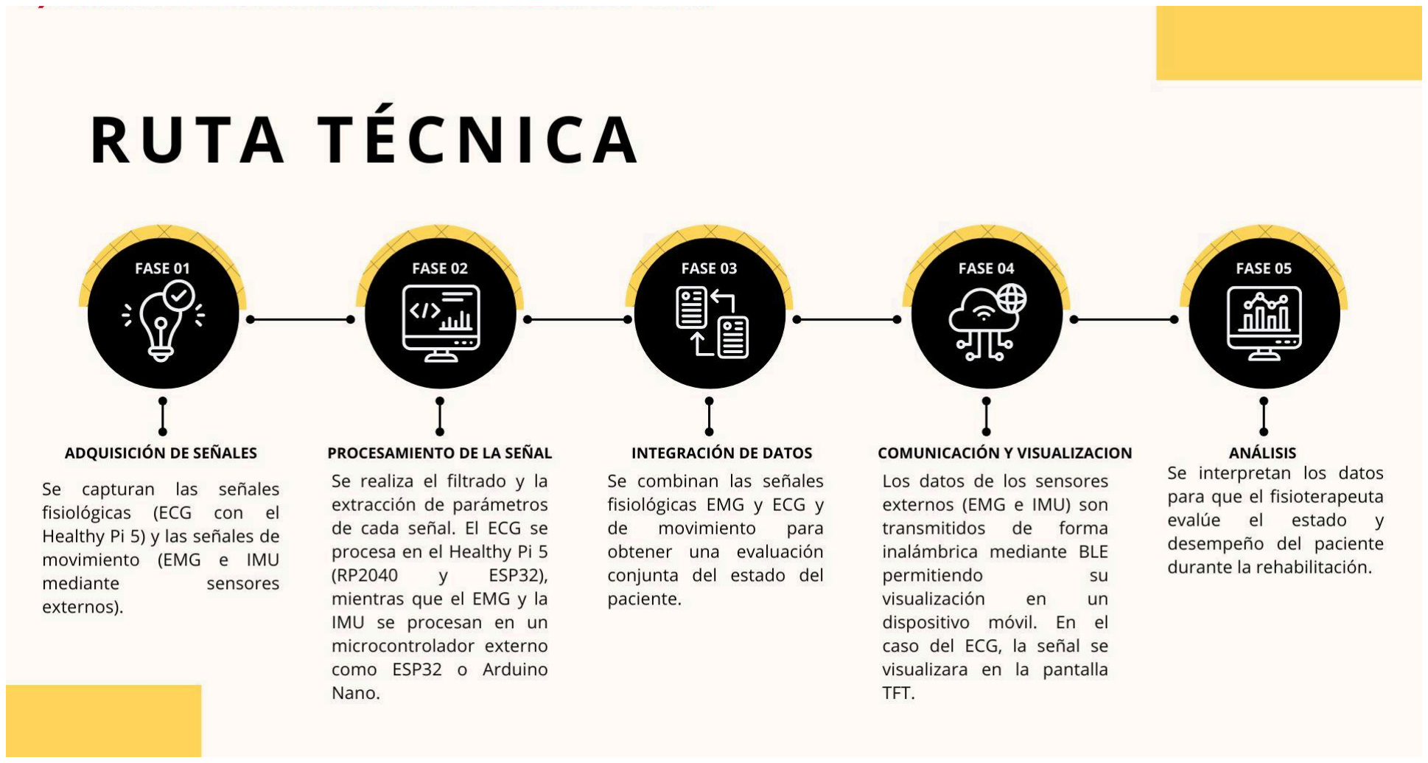
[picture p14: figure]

Fig 1. Fases de la ruta técnica del procesamiento de señales hasta su interpretación [Fuente: Elaboración propia].

v. Justificación de la ruta técnica

La ruta técnica propuesta se basa en un enfoque multimodal que integra señales como ECG, EMG e IMU, el cual ha sido ampliamente validado en la literatura para sistemas de rehabilitación [1]. Estudios han demostrado que la combinación de señales fisiológicas y de movimiento permite una evaluación más precisa del estado del paciente, mejorando el monitoreo del esfuerzo, la activación muscular y la ejecución del movimiento [2]. Asimismo, el uso de procesamiento local en sistemas embebidos y la transmisión inalámbrica (BLE) para visualización en tiempo real es una arquitectura común en dispositivos modernos de monitoreo, lo que respalda la viabilidad y aplicabilidad del sistema propuesto.

### III. Revisión bibliográfica

Solucione s | M- Trigger [3] | QSense [4] | myoMUSCL E [5] | BioGAP-Ultra [6] | Prototipo de sistema portátil para adquisición y procesamiento de señales fisiológicas orientado al control de salud ocupacional [7]
Descripci ón | Herramienta de rehabilitación para proporcionar información sobre el nivel de actividad muscular. | Dispositivo de sensores IMU +EMG para rehabilitación domiciliaria, con detección de patrones compensatorios del hombro . | Software de procesamient o y análisis de datos kinesiólogos (EMG + IMU) | Plataforma de hardware modular y portátil para adquisición sincronizada de señales biomédicas multimodales (EEG, EMG, ECG,PPG,IMU, audio) con capacidad de procesamiento de IA. | Sistema portátil vestible implementado en una prenda tipo chaleco, diseñado para la monitorización continua de variables fisiológicas y posturales durante actividades laborales, con el objetivo de detectar fatiga, estrés y riesgo musculoesquelético.

Variable medida | Actividad eléctrica muscular mediante señal EMG. | Movimiento corporal (posición, velocidad, aceleración) Actividad eléctrica muscular (activación, relajación). | Actividad Muscular (EMG) Aceleración, velocidad angular y campo magnético (IMU). | Señales fisiológicas: biopotenciales (EEG, EMG, ECG) fotopletismografía (PPG) aceleración, velocidad angular, campo magnético, audio. | Fisiológicas (ECG): frecuencia cardiaca (LPM), Variabilidad de la frecuencia cardiaca (HRV) Posturales (IMU): Ángulo torácico, Estado postural.
Tecnologí a utilizada | Sistema mTrigger (electrodos + app móvil) con retroalimentación visual en tiempo real. | Electromiografía superficial (sEMG) Sensores Inerciales (IMU) Q sense Motion(software análisis) Aplicativo móvil. | Sensor IMU Sensores Ultium EMG Software myoMUSCLE | Procesamiento: Microcontrolador GAP9 (datos + IA) Comunicación: nRF5340 (Inalámbrica) Sensores Biomédicos: ADS1298 (AFE para ECG) MAX86150 (PPG + ECG) | Hardware: ESP32, AD832 (ECG), ADS1115(ADC), MPU9250 (IMU) Comunicación: Bluetooth
Ventaja principal | Retroalimentació n en tiempo real, no invasivo | Permite detectar compensación del hombro, proporciona retroalimentación en tiempo real | Almacenamie nto en memoria y mapa muscular anatómico 3D | Sistema completo con sincronización entre múltiples nodos, diseño compacto, cuenta con IA | Monitoreo continuo y en tiempo real de variables fisiológicas y posturales en un sistema portátil de bajo costo
Limitació n principal | Depende de dispositivos tecnológicos (celular) y necesidad de supervisión profesional para uso adecuado y establecer los objetivos de contracción. | La sincronización de IMU y EMG está en ruta de desarrollo, y necesitará ayuda de terapeuta para la colocación correcta de los sensores, limitada implementación clínica | No tiene un interfaz amigable con el usuario, ya que las gráficas y los datos presentados no son fáciles de interpretar | El almacenamiento no es autónomo (requiere dispositivo externo) y la conexión entre la banda toracica y el sensor PPG de oreja es por cable | Monitoreo limitado a variables generales (cardiovasculares y posturales), sin medición directa de la actividad muscular

Tabla 1. Cuadro comparativo de referencias revisadas [Fuente: Elaboración propia]

### IV. Validación inicial de la idea de solución

Se realizó una entrevista a un profesional de fisioterapia con amplía experiencia, dicha persona se entrevistó previamente en la primera validación, por lo que sus comentarios toman mucha relevancia al conocer el avance del proyecto. Se presentó un resumen de la idea preliminar y una breve explicación de los conceptos generales y el principio de funcionamiento con un lenguaje entendible para una persona sin experiencia en ingeniería, pero con experiencia en medicina física; luego, se presentó el boceto del concepto de solución y su funcionamiento práctico. Finalmente, se realizaron preguntas para conocer si el profesional de fisioterapia encontraría útil y práctico el uso del producto; así como temas relacionados al precio, peso y características físicas, alimentación eléctrica, movimientos de rehabilitación, músculos involucrados, ergonomía y diseño.

i. Preguntas guía

Se elaboraron preguntas de introducción para evaluar si la problemática planteada por el equipo es real y crítica en la práctica diaria del fisioterapeuta. Luego, previa explicación de la propuesta de solución, se formularon preguntas relacionadas al boceto preliminar de la idea de solución.

Preguntas de introducción:

a. En tu experiencia, ¿Qué tipo de lesiones relacionadas al dolor de hombro son más comunes y que edad suele presentar los pacientes con dicha patología?
b. ¿Qué tipo de movimientos y ejercicios terapéuticos tradicionales se ejecutan durante la rehabilitación del dolor de hombro?

Preguntas sobre la solución:

a. ¿Existen otros productos similares a la idea planteada y qué tan útil sería el producto durante su trabajo terapéutico?
b. ¿Qué consideraciones de aspecto físico, seguridad y ergonomía consideraría para decidir utilizar el producto en lugar de continuar con la terapia convencional?
c. ¿Cree usted que los pacientes estén dispuestos a aceptar el uso del producto durante su rehabilitación y qué miedos o preguntas esperaría de ellos?
d. ¿De qué manera le sería más fácil o le gustaría visualizar los datos fisiológicos y de movimiento de los pacientes durante su trabajo?
e. ¿Qué precio aceptaría pagar por el producto y cómo se compara dicha cantidad con los precios de otros equipos que utiliza en su día a día?

ii. Principales hallazgos

Sobre las preguntas de introducción, la terapista refirió que el hombro doloroso es una primera patología que, de no tratarse a tiempo, podría desencadenar en dolencias más graves como el síndrome del hombro congelado, manguito rotador e incluso ruptura de los tendones de la articulación del hombro. Por otro lado, la edad más común de los pacientes con esta dolencia son jóvenes, especialmente aquellos que practican gimnasio. Respecto a los ejercicios de la terapia tradicional, la terapista mencionó que son muy comunes los ejercicios que involucren las rotaciones del hombro en los 3 ejes como aducción, abducción, etc; hizo énfasis en movimientos de la vida cotidiana como el ponerse un polo, levantar el brazo y rascarse la espalda. Por último, mencionó que los músculos del deltoides están demasiado involucrados en los ejercicios y el movimiento; mientras que el trapecio superior también, especialmente porque puede llegar a fatigarse rápidamente.

Sobre las preguntas relacionadas a la solución, la terapista manifesto kue, al menos en su trabajo, no existen otros productos se sirvan de bioseñales para poder hacer un monitoreo en tiempo real y a largo plazo de la rehabilitación del paciente; además, mencionó que sería demasiado útil contar con una herramienta como la propuesta, pues muchas veces los pacientes suelen mentir con sus respuestas fisiológicas durante el ejercicios (fingir no estar cansado), lo cual afecta mucho la rehabilitación.

Sobre los aspectos de seguridad, ergonomía y diseño, mencionó que sería primordial que tenga un bajo peso y que no sea una prenda como un polo sino un chaleco con botones, pues algunos de los pacientes no pueden ni siquiera subir la mano para ponerse un polo, también mencionó que lo ideal sería que no vaya conectado directamente al tomacorrientes, y que sería mejor que funcione con baterías y que cuente con alarmas para saber el nivel de energía y si esta prendido o apagado.

Sobre la aceptación de los pacientes, mencionó que sería muy bien aceptado, pues a los pacientes les gusta que se les atienda utilizando equipos y tecnología siempre que se pueda.

Sobre la visualización, mencionó que la información debería poder verse y entenderse rápidamente para no desperdiciar tiempo de la sesión de terapia, especialmente si pudiera visualizarse en un celular incluso sin necesidad de internet.

Por último, sobre el precio, mencionó que estaría dispuesta a pagar hasta un precio de 1500 soles (evaluando seriamente el retorno de inversión) y hasta un precio de 1000 soles “a ojos cerrados”; sin embargo, mencionó que, dadas las bondades del producto, el precio sería muy aceptable en la comunidad de terapistas.

### V. Normativas y restricciones de diseño

### 1. Seguridad Eléctrica y Funcionalidad Básica (IEC 60601-1)

El dispositivo debe funcionar sin la conexión directa de la red eléctrica comercial sino se hará uso de baterías de 5V para eliminar el riesgo de accidentes eléctricos al paciente.
El diseño de la carcasa de la PCB debe prevenir cualquier contacto con el usuario con los componentes electrónicos para prevenir accidentes.
2. Biocompatibilidad de Materiales (ISO 10993)
Los electrodos que están en contacto con la superficie de la piel deben ser de grado médico y biocompatibles para un monitoreo continuo sin dañar la piel del paciente.
El material del soporte del hombro utilizará tela de grado médico biocompatible para evitar irritaciones por roce y una ventilación adecuada que no perjudique los circuitos.
3. Ciclo de Vida del Software de Dispositivos Médicos (IEC 62304)
La aplicación móvil, el Healthy Pi 5 y el ESP32 deben desarrollarse bajo la garantía de que la visualización de las gráficas de ECG y EMG sean precisas y en tiempo real.
El software debe incluir protocolos de privacidad para garantizar la integridad de la información fisiológica transmitida por BLE de los pacientes.

### VI. Lista de exigencias

Lista de exigencias

Proyecto NEMO: Neuromuscular and Effort Monitoring

Fechas: 09/04/2026

Elaborado:

Luis Luque(LL),
Anthony Callupe(AC)
Ándre Vallejo (AV),
Daniel Cárdenas(DC),
Mishelle Llano(ML),
André Palomino(AP)
Usuario | Pacientes en rehabilitación de miembro superior
Contexto real | Uso de un prototipo de monitoreo continuo similar a un wearables que ayude a la rehabilitación del miembro superior, enfocado en el hombro doloroso.
Fecha | Deseo / Exigencia | Descripción | Encargado
3/04/2026 | E | Función Principal: El producto debe servir para monitorear el rendimiento del paciente mediante gráficas ECG y EMG de monitoreo continuo | Todos
3/04/2026 | E D | Geometría: Por el momento se espera que tenga una geometría similar a un proyecto de hombro que pueda cubrir gran parte del torso superior hasta el antebrazo. Sería ideal que el producto final no ocupe tanto espacio en el cuerpo del paciente, ya que para distintos usuarios puede llegar a ser incómodo | Todos

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
d: Todo el sis
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
a. Además se hace uso de Norma IEC 60601-1, para funcionalidad básica de dispositivos electrónicos e ISO 10993, para la evaluación biológica par,a dispositivos biomédicos[8,9] Los materiales tanto para la carcasa protectora como la tela se espera que no dañen el entorno. | AV,

A

C

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

### VII. Primer boceto de la solución

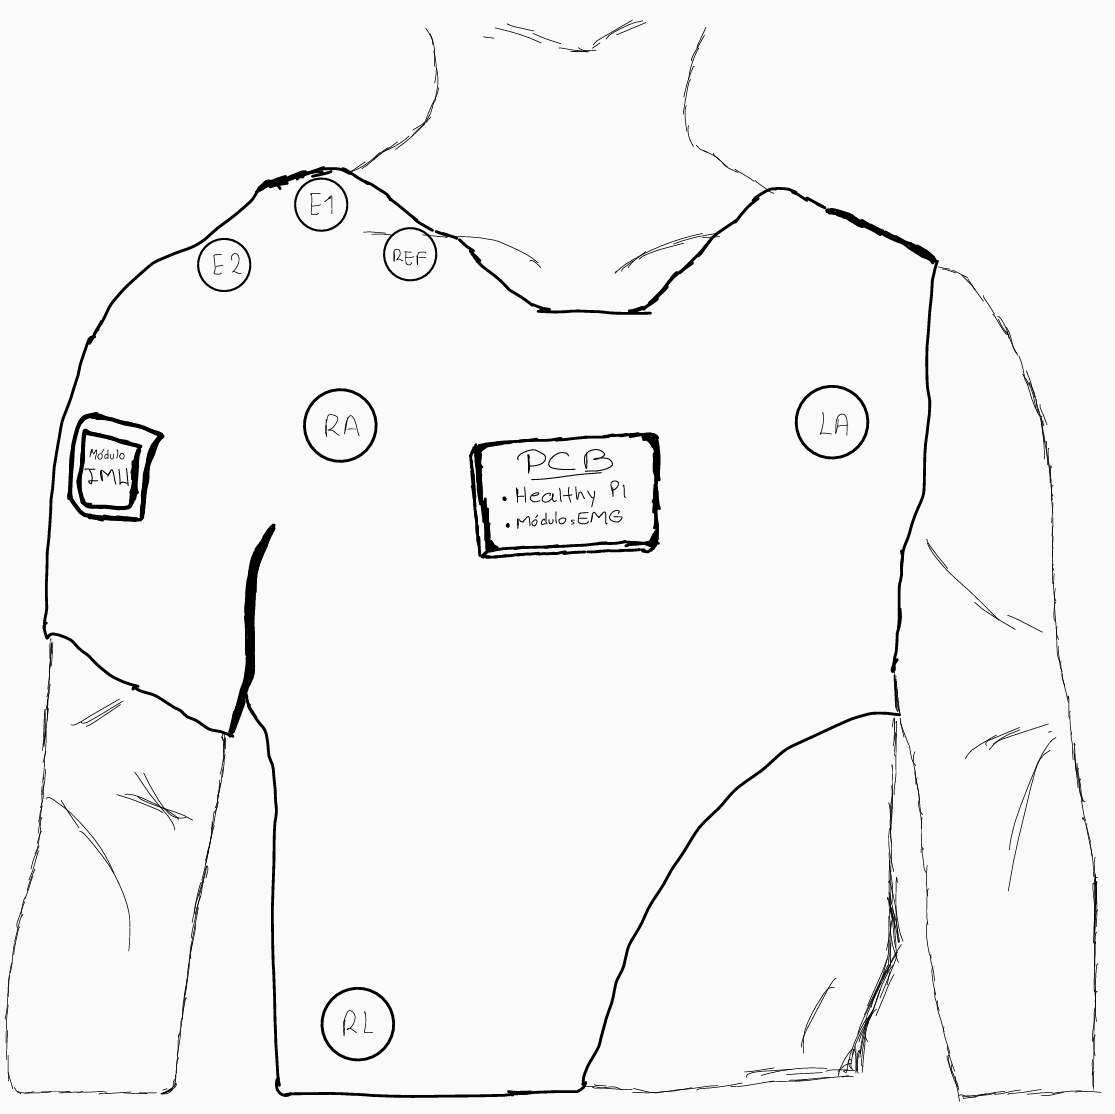
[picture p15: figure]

Fig 2. Boceto general del dispositivo junto a la prenda.

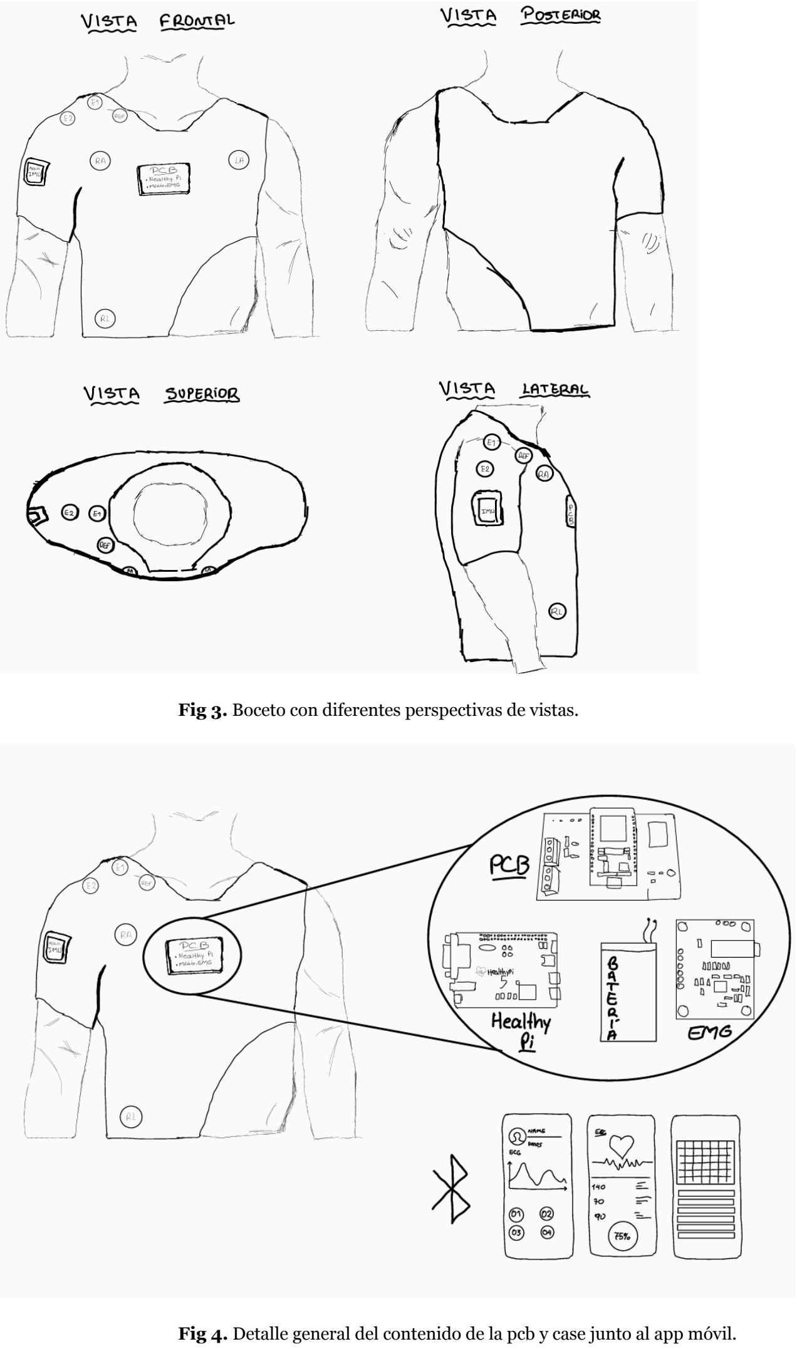
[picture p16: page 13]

Fig 3. Boceto con diferentes perspectivas de vistas.

Fig 4. Detalle general del contenido de la pcb y case junto al app móvil.

### VIII. Bibliografía

[1] Y. Li, X. Zhang, Y. Gong, Y. Cheng, X. Gao y X. Chen, “Motor function evaluation of hemiplegic upper-extremities using data fusion from wearable inertial and surface EMG sensors,” Sensors, vol. 17, no. 3, p. 582, Mar. 2017, doi: 10.3390/s17030582.
[2] S. Zhao, J. Liu, Z. Gong, Y. Lei, X. Ouyang, C. C. Chan y S. Ruan, “Wearable physiological monitoring system based on electrocardiography and electromyography for upper limb rehabilitation training,” Sensors, vol. 20, no. 17, p. 4861, Aug. 2020, doi: 10.3390/s20174861.
[3] “The science,” mTrigger. https://mtrigger.com/pages/the-science
[4] Coenlauwerijssen, “Sensor IMU + EMG para la rehabilitación domiciliaria de la extremidad superior tras un accidente cerebrovascular QSense Motion,” QSense-Motion,
Dec. | 10, | 2025.
https://qsense-motion.com/es/sensor-imu-emg-para-la-rehabilitacion-domiciliaria-tras-un-accidente-cerebrovascular/
[5] | “Módulo | de | software | de | medición | myoMUSCLE
TM,” | MedicalEXPO.
https://www.medicalexpo.es/prod/noraxon/product-70808-1043702.html
[6] S. Frey et al., "BioGAP-Ultra: A Modular Edge-AI Platform for Wearable Multimodal Biosignal Acquisition and Processing," in IEEE Transactions on Biomedical Circuits and Systems, doi: 10.1109/TBCAS.2026.3652501.
[7] A. S. C. Jonathan, “Desarrollo de un prototipo de sistema portátil para la adquisición y procesamiento de señales fisiológicas orientado al control de la salud ocupacional,” 2026. https://dspace.ups.edu.ec/handle/123456789/32721
[8] Evaluación biológica de dispositivos médicos - Parte 1: Evaluación y ensayos dentro de un proceso de gestión del riesgo, ISO 10993-1:2018, Organización Internacional de Normalización,2018.
https://www-iso-org.translate.goog/standard/72704.html?_x_tr_sl=en&_x_tr_tl=es&_x_tr_hl=es&_x_tr_pto=tc (https://www-iso-org.translate.goog/standard/72704.html?_x_tr_sl=en&_x_tr_tl=es&_x_tr_hl=es&_x_tr_pto=tc)
[9] Software de dispositivos médicos - Procesos del ciclo de vida del software, IEC 62304:2006, Comisión Electrotécnica Internacional, 2006. https://www.iso.org/standard/38421.html
- https://healthypi.protocentral.com/06-Hooking_up_the_Sensors/
- https://github.com/Protocentral/protocentral_healthypi_5/tree/main?tab=readm

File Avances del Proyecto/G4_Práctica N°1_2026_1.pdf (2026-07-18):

## UNIVERSIDAD PERUANA CAYETANO HEREDIA INGENIERÍA BIOMÉDICA

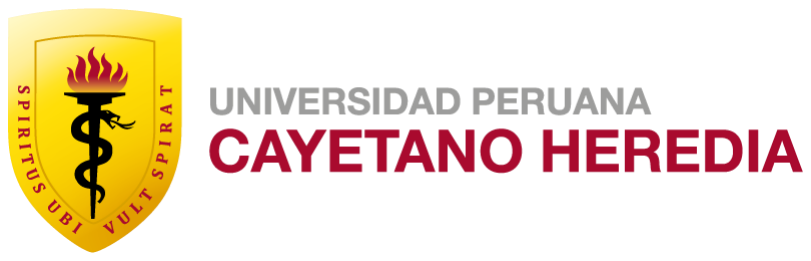
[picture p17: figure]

# PRÁCTICA DE INSTRUMENTACIÓN BIOMÉDICA

# Declaración y Validación Inicial de la Problemática Clínica y Tecnológica en

Dispositivos Biomédicos.

# [Práctica N°1]

### GRUPO N° 4 - H1:

### Llanos Guerrero, Mishelle - 70946842 Vallejo Canchanya, Andre - 73639949 Cárdenas Paniagua,Daniel - 75347191 Callupe Quispe, Anthony - 72423722 Luque Prado, Luis - 79136683 Palomino Mozo, André Alexis - 74036832

2026 -1

Monitoreo | Fisiológico | y | de | Movimiento | en

## rehabilitación de miembro superior

### I. Delimitación del proyecto asignado. Indicar la línea de proyecto

seleccionada por el grupo.

El grupo decidió trabajar la línea de proyecto 15 “Monitoreo fisiológico y de movimiento en rehabilitación de miembro superior”, para lo cual se necesita delimitarlo según el contexto de uso esperado, usuario objetivo y necesidad clínica.

i. Contexto de uso:

La rehabilitación física se puede realizar en diversos contextos como hospitales o en domicilio, con presencia de un personal de terapia o no. Este proyecto se enfocará en centros de terapia física de hospitales, clínicas o privados y con la asistencia de al menos un especialista de terapia física, por lo tanto el contexto se define como hospitalario.

ii. Usuario objetivo:

Se definió el usuario objetivo usando aspectos de exclusión y exclusión en base a cinco criterios: rango de edad, ocupación, estado de salud, duración promedio de la rehabilitación y lesión prevalente.

a. Criterios de inclusión
●Hombres y mujeres adultos 18 a 30 años
●Ocupación de estudiantes o trabajadores ●Condición física previa de nivel promedio o activa ●Diagnóstico de lesiones relacionadas al hombro ●En fase activa de rehabilitación supervisada
●Sin comorbilidades sistémicas
b. Criterios de exclusión
●Enfermedades metabólicas como Diabetes u otros
●Enfermedades oncológicas activas
●Trastornos cardiovasculares o cardio respiratorios diagnosticados
●Otras condiciones que puedan alterar la respuesta fisiológica al ejercicio

En este sentido, se puede resumir al usuario objetivo como un adulto joven de 18 a 30 años, estudiante o trabajador con condición física promedio o activa, diagnosticado con alguna lesión asociada al hombro y en fase activa de rehabilitación supervisada.

iii. Necesidad clínica:

Durante la rehabilitación, la mayoría del tiempo no existe una manera objetiva de monitorear la realización correcta de los ejercicios ni la evolución en el tiempo [1]; por ejemplo, en Alemania, solamente el 31% de los fisioterapeutas utilizan medidas objetivas [2].

En este sentido, los fisioterapeutas necesitan una herramienta objetiva y sencilla de entender para el monitoreo en tiempo real basada en datos fisiológicos y de movimiento para poder hacer seguimiento de la ejecución de los ejercicios y la evolución de los pacientes durante su rehabilitación.

iv. Delimitación de la problemática:

Se delimitará la problemática teniendo en cuenta el usuario objetivo definido y la lesión que padece, el contexto hospitalario y la necesidad clínica hallada previamente. La problemática delimitada en 3 líneas sería la siguiente:

“El ajuste de ejercicios durante la rehabilitación supervisada en adultos jóvenes con lesiones asociadas al hombro se basa en criterios subjetivos. La ausencia de seguimiento cuantitativo de la ejecución y evolución limita la evaluación objetiva del progreso terapéutico”.

### II. Sustento inicial de la problemática

i. Estadísticas Internacionales

A nivel mundial, los trastornos musculoesqueléticos (TME) comprenden más de 150 trastornos que afectan al sistema locomotor; suelen causar dolor y constituyen una de las principales causas de discapacidad a nivel global. Según la Organización Mundial de la Salud (OMS), se estima que aproximadamente 1710 millones de personas padecen TME en el mundo [3]. Estas afecciones se presentan en mayor frecuencia en la espalda, seguida de los miembros superiores y los miembros inferiores [4]. En relación con la localización del dolor, el estudio: “Prevalencia e impacto de los trastornos musculoesqueléticos”, realizado por el Colegio Americano de Reumatología en 2004, reveló que el dolor en extremidades superiores (incluyendo hombro y brazo) son comunes en la población general y a menudo se asocia con signos físicos que sugieren trastornos específicos de las extremidades superiores [5].

Asimismo, la prevalencia anual de estos trastornos del miembro superior pueden variar entre 2,3% y 41%, alcanzando hasta 53% en poblaciones laborales, evidenciando su alta frecuencia, especialmente en contextos laborales [6]. Adicionalmente, el dolor de hombro, como una de las principales afecciones del miembro superior, presenta una prevalencia anual entre 7% y 26%, incrementándose con la edad y factores ocupacionales [7]. Cabe destacar que hasta el 50% de la población puede experimentar al menos un episodio de dolor de hombro al menos una vez al año, lo que evidencia su alta frecuencia y relevancia. En el ámbito laboral, este tipo de dolor se asocia a factores de tensión como la falta de control en el trabajo, las posturas con los brazos elevados y el uso de herramientas manuales [8].

Por otro lado, la necesidad de rehabilitación es alta, ya que la OMS indica que en países de ingresos bajos y medios, más del 50% de las personas no acceden a los servicios de rehabilitación que requieren lo que agrava la discapacidad funcional [9].

ii. Estadísticas Nacionales

En el Perú, la problemática se ve agravada por limitaciones en el sistema de salud. Según el articulo: “ Grado de dolor y trastornos musculoesqueléticos más frecuentes en pacientes del área de terapia física y rehabilitación en un centro médico de Villa El Salvador (Lima, 2022)”, la adherencia al tratamiento fisioterapéutico es baja, ya que el 56,4% de los pacientes abandonó o no cumplió adecuadamente con la rehabilitación, perjudicando su proceso de recuperación [10].

Asimismo, el acceso a servicios especializados es limitado, debido a que solo existen aproximadamente 42 médicos especialistas por cada 100.000 habitantes, lo que evidencia una brecha en el acceso a atención médica [11]. En cuanto a la rehabilitación, en el año 2018 se registraron alrededor de 12 000 terapistas físicos, de los cuales el 70% se encontraba en Lima, generando desigualdad en la atención en otras provincias del país [12] .

Esto demuestra la relevancia en el contexto del miembro superior (hombro y brazo), debido a que existe una alta prevalencia de estas afecciones a nivel mundial, las cuales afectan directamente la funcionalidad del brazo y la calidad de vida de los pacientes. Además, en el Perú se evidencia una brecha significativa en el acceso a servicios de rehabilitación, así como una baja adherencia al tratamiento, lo que dificulta una recuperación adecuada.

iii. Grupo etario

Existe una prevalencia del 11,6 % de dolor crónico de hombro en adultos jóvenes entre 15 y 34 años de edad, lo que sugiere que 1 de cada 9 personas experimentan dolor. Estas cifras de prevalencia no varían según el género ni ubicación geográfica [13]; por lo que, este porcentaje puede ser extrapolado al Perú. Además, esto sustenta nuestra delimitación del grupo etario elegido, en este caso de 18 a 30 años de edad, demostrando que este es un problema relevante.

iv. Carencias

Existe una marcada falta de monitoreo objetivo basado en datos fisiológicos del paciente en tiempo real [1]; por ejemplo, en Alemania, solamente el 31% de los fisioterapeutas utilizan medidas objetivas; mientras que un 26% lo hace muy raramente [2]. Además, incluso si se cuenta con equipos para un monitoreo cuantitativo, estos suelen ser caros y requieren personal especializado [14].

### III. Análisis preliminar con TRL y GAITS

i. Analizar la problemática desde TRL

Ubicar preliminarmente la propuesta en un nivel TRL y justificar brevemente esa ubicación. Actualmente nos encontramos en la etapa 2, y el principal motivo es tanto la necesidad de conceptos tecnológicos y bocetos preliminares de la posible solución, que son necesarios para la etapa 3 y superiores.
Si bien tenemos datos y estadística referente al tema, pero sin el diseño conceptual y los bocetos preliminares (TRL 2), no se puede seleccionar el hardware (TRL 3), sin hardware no se pueden procesar las señales (TRL 4), y sin eso, no hay validación clínica posible.

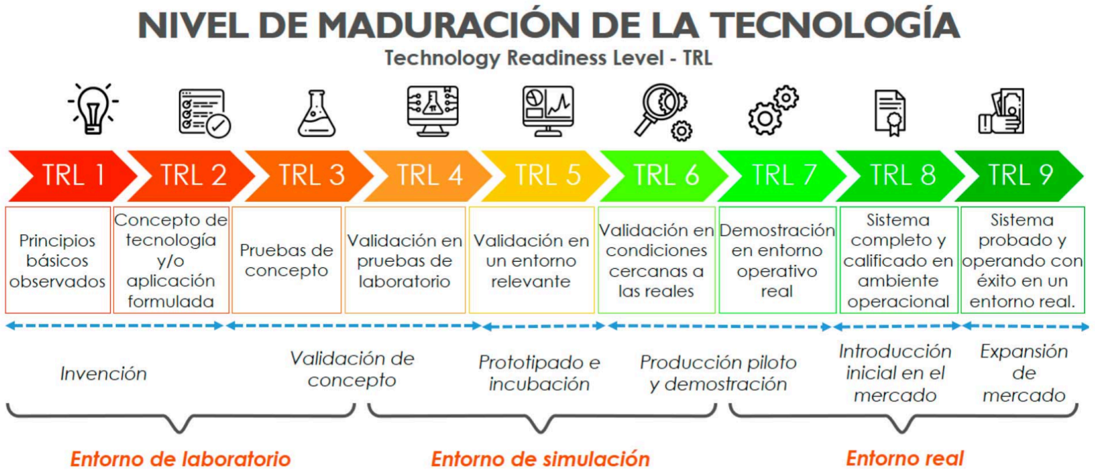
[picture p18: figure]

Figura 1. Escalas por nivel de los TRL.

ii. Analizar la problemática desde GAITS en cuatro dimensiones

Los GAITS dan seguimiento al progreso de tecnologías médicas y de salud, evaluando su madurez y el impacto potencial en los sistemas sanitarios y se subdividen en dominios.

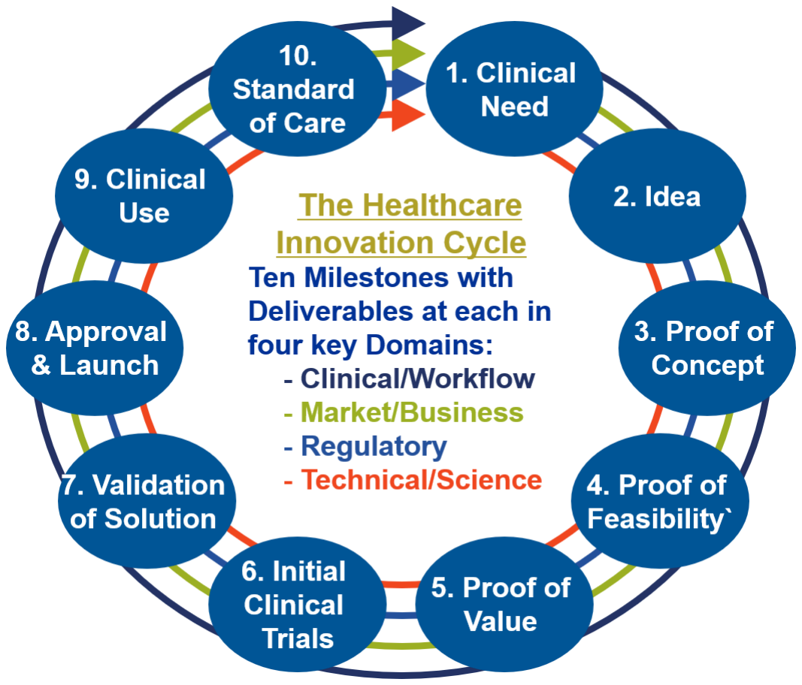
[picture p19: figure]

Figura 2. Dominios y niveles de los GAITS.

Si bien hemos superado la Etapa 1 validando la necesidad clínica a través de datos y estadística referentes a la rehabilitación de miembro superior, aún nos encontramos definiendo los conceptos y bocetos preliminares de la solución. El principal motivo por el cual no hemos escalado a la Etapa 3 (Prueba de Concepto) es que esta metodología exige un avance simultáneo en cuatro dominios clave. Para ascender, no solo requerimos consolidar la arquitectura de la tecnología, sino también definir requerimientos clínicos específicos con especialistas, perfilar la estrategia regulatoria del dispositivo y establecer un mapeo inicial del usuario frente al comprador económico.

a. Evaluación clínica
Evalúa si realmente ayuda a mejorar la salud ,mediante evidencia médica. Para subir de nivel, necesitamos definir con fisioterapeutas o médicos cuáles son las variables de movimiento o fisiológicas exactas que necesitan que el dispositivo mida para que realmente aporte valor en la terapia, cosa que tenemos parcialmente.
b. Evaluación Tecnológica
Este apartado guarda gran relación con los TRL, por ello necesitamos consolidar los bocetos principales y definir la arquitectura física del hardware para poder ascender.
c. Evaluación regulatoria
Todo equipo de monitoreo fisiológico tiene implicaciones normativas. Para avanzar, se necesita un análisis preliminar de qué clase de dispositivo médico será y qué normativas de bioseguridad o de dispositivos electrónicos médicos aplican.
d. Usabilidad / contexto de uso
Para aumentar la etapa primero debemos definir estrictamente hacia quien debe ser dirigida esta solución, hacia el paciente en rehabilitación o al doctor encargado de supervisar dicha recuperación.

### IV. Revisión breve de soluciones existentes

i. The use of wearable sensors to assess and treat the upper extremity after stroke: a scoping review (https://pmc.ncbi.nlm.nih.gov/articles/PMC9912423/)

Este trabajo analiza 43 artículos sobre el uso de sensores portátiles como IMUs y acelerómetros, para evaluar y apoyar la rehabilitación del miembro superior en pacientes con accidente cerebrovascular. Se utilizó la guía de PRISMA para extraer información para procesamiento, análisis y resultado de datos. Se realizó una revisión sistemática de la base de datos PubMed, Embase, Web of Science y CINAHL. El objetivo fue utilizar datos de movimiento para mejorar el monitoreo. La adquisición de datos se puede realizar mediante sensores colocados en la muñeca o en otro segmento del cuerpo, ya sea en entornos clínicos u hogares. El procesamiento incluye filtrado de señal y métodos de Machine Learning como redes neuronales, random forest y SVM. Los resultados muestran precisión en la clasificación de parámetros cinemáticos del brazo. En sesiones terapéuticas, los sensores generan retroalimentación como vibraciones o alertas sonoras y visuales. Sin embargo, existen limitaciones en las soluciones revisadas, como la falta de consenso en la estandarización de metodologías, hay una variabilidad en el número y ubicaciones de sensores y dependencia de algoritmos complejos [15].

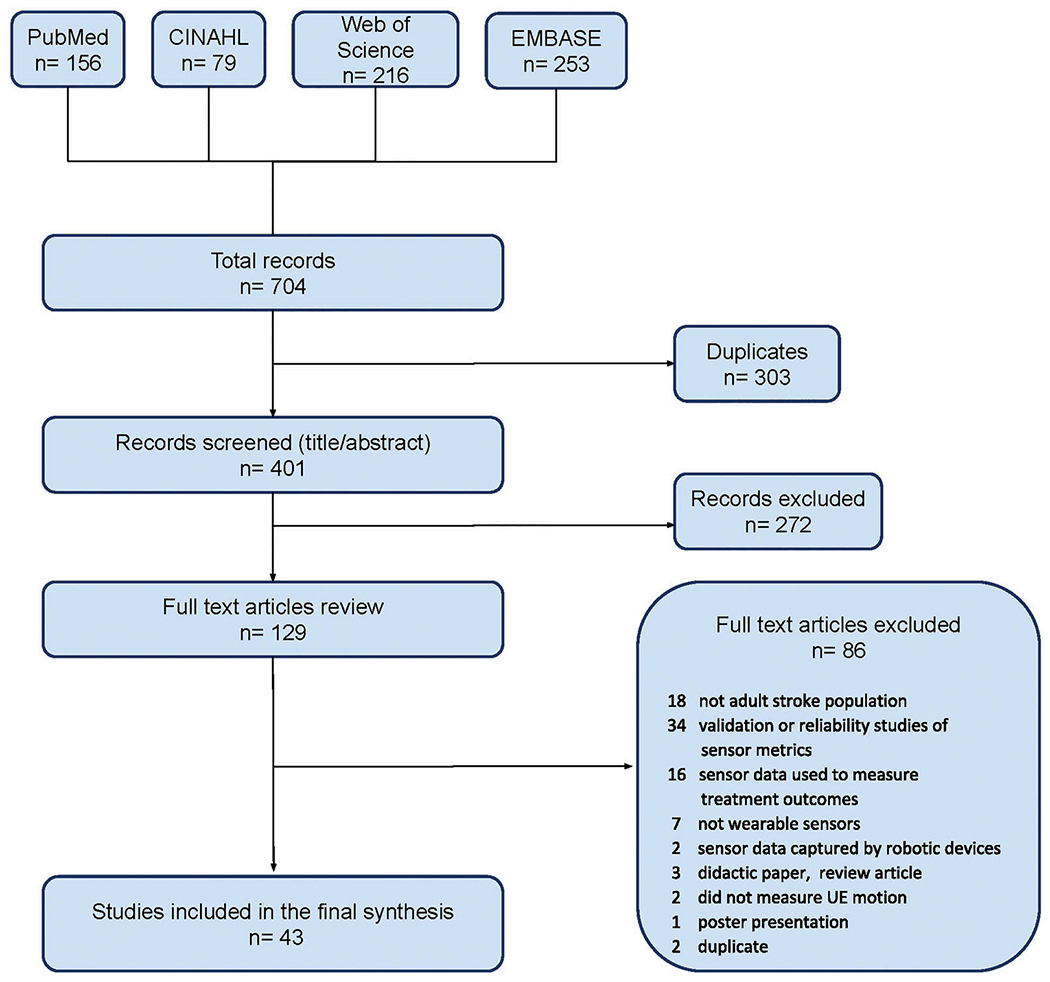
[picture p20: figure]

Figura 3. Diagrama de flujo del proceso de selección y revisión de los estudios incluidos.

ii. Propuesta de juego serio enfocado a la rehabilitación muscular de miembro superior (https://repository.umng.edu.co/server/api/core/bitstreams/ea059aea-1db1-44a1-a882-a15f1bc1f898/content)

Esta propuesta de investigación es sobre el desarrollo de un juego serio orientado a la rehabilitación del miembro superior en pacientes que han sufrido un accidente cerebrovascular (ACV). El objetivo es mejorar la movilidad, fuerza y adherencia al tratamiento mediante una experiencia interactiva que combine captura de movimiento y análisis de señales musculares. Actualmente, la rehabilitación se basa en ejercicios repetitivos que suelen ser poco motivadores. Como alternativa, los juegos serios han sido implementados utilizando sensores de movimiento como Kinect y realidad virtual. Sin embargo, estas soluciones se enfocan solo en la experiencia del usuario más no de la medición objetiva del esfuerzo o fatiga muscular. Esta propuesta usa captura de movimiento mediante Kinect y una sistema de electromiografía para registrar la actividad muscular basado en Biosignalsplux, estas señales son procesadas y analizadas mediante algoritmos de Machine Learning, permitiendo detectar niveles de fatiga muscular. Los resultados obtenidos de 30 participantes, permitieron generar una base de datos de señales EMG, estas a su vez fueron filtradas (30-150Hz) y transformadas para mejorar su análisis, demostrando una viabilidad para detectar fatiga muscular. Como resultado, el sistema permite una rehabilitación personalizada, mejorando la motivación del paciente usando retroalimentación objetiva. No obstante, presenta limitaciones como la necesidad de procesamiento offline, pruebas de población no clínica y la falta de validación en pacientes reales con ACV [16].

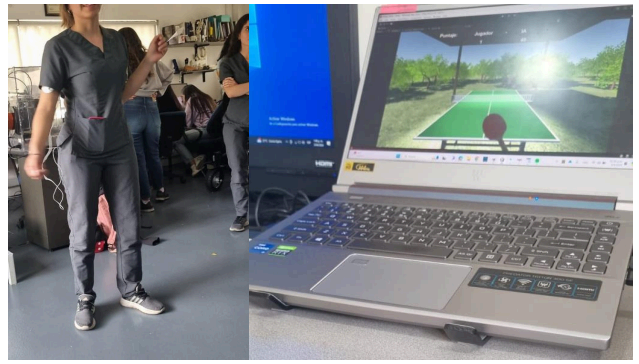
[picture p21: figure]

Figura 4. Evidencias de una de las pruebas realizadas.

iii. | Wearable | Physiological | Monitoring | System | Based | on
Electrocardiography | and | Electromyography | for | Upper Limb
Rehabilitation Training (https://www.mdpi.com/1424-8220/20/17/4861)

Este trabajo propone el desarrollo de una sistema wearable de monitoreo fisiológico para la rehabilitación del miembro superior, integrando sensores de electrocardiografía (ECG) y electromiografía (EMG). El objetivo es prevenir sobreesfuerzos, monitorear la fatiga y mejorar la efectividad del tratamiento, especialmente en terapias asistidas como guantes robóticos. Actualmente, la rehabilitación asistida se evalúa principalmente mediante mediciones antes y después de la terapia, sin un previo monitoreo continuo durante el entrenamiento. Además existe una limitada disponibilidad de terapeutas y altos costos, lo que dificulta el seguimiento constante del paciente, sobre todo en entornos domiciliarios. La propuesta consiste en un sistema compuesto por un sistema wearable con sensores ECG y EMG, y una guante robótico para asistencia en movimientos y una plataforma de software que usa Bluetooth. Las señales fisiológicas son filtradas, amplificadas, digitalizadas y analizadas en tiempo real. El EMG permite monitorear la actividad muscular durante movimientos como flexión de dedos o muñeca, mientras que el ECG permite evaluar el estado fisiológico del usuario mediante mediciones de la frecuencia cardiaca (HRV). El sistema emplea algoritmos SVM para clasificar estados de fatiga y ajustar el entrenamiento, lo que permite una retroalimentación continua. Sin embargo, existen limitaciones como la complejidad del sistema, dependencia del hardware especializado y la necesidad de validación en contextos clínicos más amplios [17].

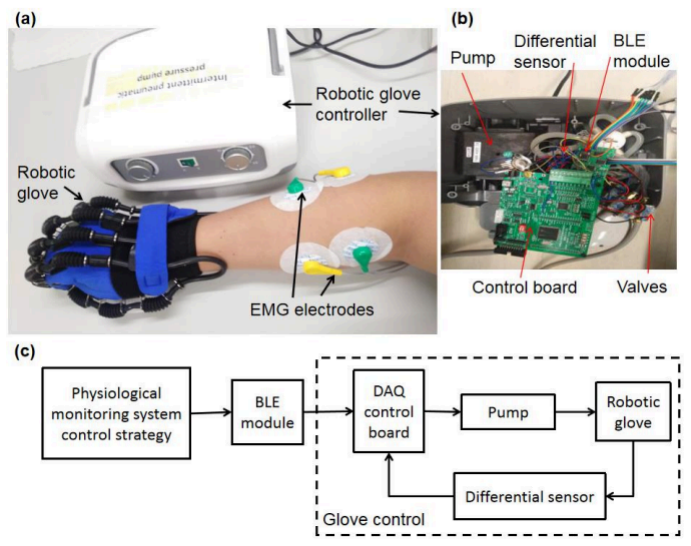
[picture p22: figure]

Figura 5. Sistema de monitorización fisiológica integrado en un guante robótico neumático para entrenamiento de rehabilitación de la mano: (a) el sistema del guante robótico; (b) el controlador; (c) el diagrama de flujo de trabajo.

iv. Dispositivo portátil para la rehabilitación del miembro superior (https://patents.google.com/patent/ES2431056T3/es)

Esta patente describe el desarrollo de un dispositivo portátil orientado a la rehabilitación del
miembro | superior | en | pacientes | con | discapacidades | neurológicas | o
musculoesqueléticas, como derivación de accidente cerebrovascular (ACV). El dispositivo incluye apoyabrazos, base móvil, sensores de movimiento, sensores de fuerza y medios de sujeción. Actualmente, la rehabilitación se da en entornos clínicos mediante ejercicios repetitivos guiados por fisioterapeutas. Sin embargo, son limitadas por el tiempo, el costo y la disponibilidad de personal especializado. Este dispositivo incorpora sensores de movimiento y fuerza para un próximo registro y análisis de datos en tiempo real. Permite su uso en entornos tele-rehabilitación, ya que puede conectarse a través de internet para una supervisión del progreso del paciente. No obstante, presenta limitaciones relacionadas con la necesidad de validación clínica a gran escala y la posible integración de sensores para un análisis fisiológico de la actividad muscular [18].

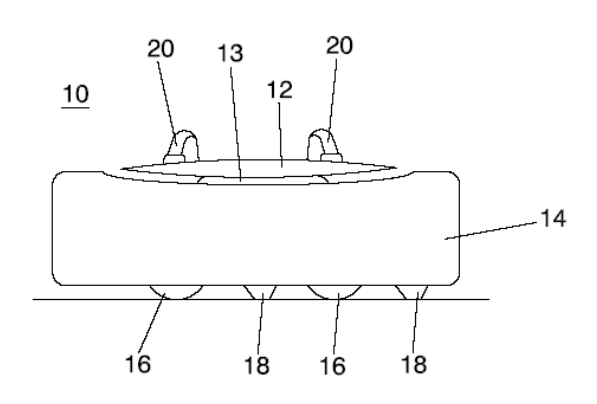
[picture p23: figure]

Figura 6. Vista del dispositivo de captura de movimiento y sensores EMG colocados en el brazo del paciente.

v. Dispositivo de asistencia de rehabilitación y programa para controlar el dispositivo de asistencia de rehabilitación (https://patents.google.com/patent/ES2693095T3/es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)

Este trabajo propone el desarrollo de un sistema wearable para la rehabilitación de extremidades, que permite monitorear y evaluar el movimiento del usuario en tiempo real. El sistema integra un soporte para la extremidad que facilita la movilidad asistida y sensores que capturan información del movimiento durante los ejercicios. La información de entrenamiento, junto con los parámetros de movimiento obtenidos, se almacenan para su análisis y evaluación mediante algoritmos. El sistema genera retroalimentación sobre el tipo de movimiento del brazo y predice el desempeño basándose en datos previos de otros pacientes. Posee una interfaz que permite visualizar la información de los entrenamientos, movimientos registrados y evaluación generada. Presenta limitaciones en la complejidad del hardware y la necesidad de calibración, la validación clínica en entornos domésticos y la dificultad de uso para pacientes con movilidad severamente restringida [19].

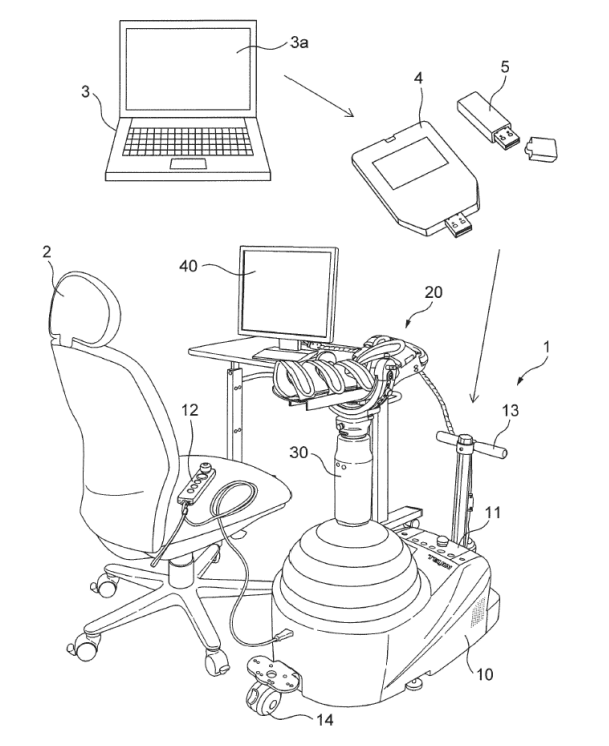
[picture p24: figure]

Figura 7. Vista en perspectiva de un sistema de soporte para rehabilitación.

### V. Cuadro comparativo breve

| Solución 1 (MDPI -Artículo Científico) | Solución 2 (Patente ES2693095T3) | Solución 3 (Patente ES2431056T3)
Nombre de la solución | Sistema portátil de monitorización fisiológica basado en ECG y EMG para el entrenamiento con guante robótico. | Dispositivo de asistencia de rehabilitación y programa de control. | Dispositivo portátil (robot móvil) para la rehabilitación del miembro superior.
Función principal | Monitorizar en tiempo real el estado fisiológico (fatiga, excitación) durante la rehabilitación e integrar esta información para controlar y asistir el movimiento mediante un guante robótico. | Soportar y guiar la extremidad durante ejercicios repetitivos, evaluar el movimiento realizado y predecir la recuperación futura del paciente comparando sus | Monitorear la extensión y elevación en superficie plana, con el antebrazo fijo para evitar compensaciones.

| | datos con una base de datos clínica.
Usuario objetivo | Pacientes con ACV u otras condiciones que requieren rehabilitación prolongada del miembro superior | Pacientes con daño motor parcial y fisioterapeutas que guían su rehabilitación | Personas con trastornos neurológicos o musculoesqueléticos con dificultad para realizar extensión y elevación simultáneas.
Señal o variable biomédica utilizada | Señales electrofisiológicas: ECG y EMG para medir la frecuencia cardíaca y la actividad muscular. | Variables cinemáticas: datos de movimiento como rango angular y posición al desplazar la sujeción. | Variables cinemáticas y cinéticas: posición, velocidad, aceleración, orientación del brazo y fuerza de elevación aplicada al dispositivo.
Ventajas | - Adapta el esfuerzo del guante robótico al nivel de fatiga muscular real del paciente. - Ideal para monitorización continua en el hogar. | - Reduce la fatiga del terapeuta al automatizar los movimientos precisos. - Estandariza la calidad de la terapia. | - Aísla el movimiento del hombro al fijar el codo/antebrazo. -Diseño simple, económico y portátil frente a exoesqueletos fijos complejos.
Limitaciones | - Requiere la correcta colocación de múltiples electrodos en la piel. - Susceptible a artefactos de movimiento en las señales de ECG/EMG durante ejercicios intensos. | - Es un equipo fijo, robusto y generalmente limitado al uso clínico/hospitala rio. - Depende de bases de datos preexistentes para que la predicción de recuperación sea precisa. | -Requiere forzosamente una superficie plana y amplia (mesa) para operar. -Se centra en hombro y codo; requiere acoplar módulos extra para rehabilitar la muñeca o el agarre manual.

### VI. Validación inicial con stakeholders

i. Stakeholder entrevistado

Se realizó una entrevista a una fisioterapeuta con amplia experiencia en rehabilitación física, quien nos brindó información relevante para comprender las limitaciones del seguimiento clínico.

ii. Preguntas guía

a. En tu experiencia, ¿Qué tipo de pacientes con afecciones en miembro superior atiende con mayor frecuencia y cuáles son los objetivos principales que busca alcanzar al inicio de un tratamiento?
b. ¿En qué criterios se basa para determinar que un paciente está mejorando realmente y cómo decide el momento oportuno para avanzar hacia ejercicios de mayor exigencia?
c. Durante la ejecución de los ejercicios, ¿cuáles son los errores de técnica o patrones de compensación más comunes que detecta y qué aspectos considera críticos para definir un movimiento como "bien hecho"?
d. ¿Qué señales físicas o parámetros fisiológicos le indican que un paciente ha llegado a su límite de fatiga y cómo le ayudaría contar con esta información en tiempo real?
e. Actualmente, ¿qué limitaciones encuentra en las herramientas clínicas convencionales y qué tipo de información interna del paciente le gustaría visualizar de manera automática?
f. ¿Cuáles son los riesgos que más le preocupan durante la rehabilitación y qué características de seguridad o límites de movimiento debería tener un dispositivo para que sea confiable?
g. Desde su experiencia, ¿cuáles son las principales barreras que impiden que un paciente cumpla con sus ejercicios en casa y qué tipo de seguimiento o acompañamiento podría marcar la diferencia?
h. Si se implementara un nuevo sistema de apoyo, ¿qué variables específicas debería medir, qué tipo de alertas visuales necesitaría y cómo debería ser su diseño para que realmente se use en la práctica diaria?

iii. Principales hallazgos

Se identificó que la mayoría de los pacientes presentan afecciones de miembro superior como problemas en tendones como epicondilitis y epitrocleitis, lesiones comunes en los tenistas como el síndrome del túnel carpiano y en adultos mayores presentaron lesiones del manguito rotador y hombro doloroso.

Los pacientes suelen compensar movimientos sin notar que lo hacen por dolor o falta de masa muscular. Un error crítico es que los pacientes creen estar recuperados cuando logran levantar el brazo, aunque lo hagan con dolor o mala técnica, lo que genera complicaciones como el hombro congelado. La decisión de avanzar en la exigencia se basa actualmente en la palpación clínica, observación de expresiones faciales, el cumplimiento de ejercicios en casa y si el paciente es obediente.

La terapeuta indicó la necesidad de monitorear en tiempo real la frecuencia cardíaca (ECG) y la presión arterial ya que muchos pacientes no comunican que presentan ciertas condiciones como la hipertensión o la diabetes, lo que ha provocado desmayos durante las sesiones.

Actualmente no utilizan herramientas tecnológicas avanzadas, el trabajo es mayormente clínico y observacional ya que hay una falta de herramientas portátiles que permitan ver el estado interno de los tendones o fracturas en tiempo real, similar a un “rayos X portátil” para confirmar la mejora real en los pacientes y evitar trabajar sobre diagnósticos erróneos de equipos en mal estado en el sistema público.

Para que el dispositivo sea usado por los pacientes, debe ser económico, portátil, fácil de usar con información clara y entendible, y no estar conectado a la corriente para evitar el miedo a descargas eléctricas. Además, debe incluir alertas visuales y sensores que no restrinjan el movimiento y que faciliten el seguimiento tanto para el terapeuta como para el paciente. La especialista resaltó en la inclusión en fisioterapia y educación, señalando que muchas veces no se toma en cuenta a personas con discapacidades como sordera o ceguera es por eso que debe de estar diseñado para adaptarse a cualquier condición del paciente.

La fisioterapeuta indicó que hay baja adherencia al tratamiento por factores económicos y falta de compromiso a su vez enfatiza que es indispensable el acompañamiento del fisioterapeuta durante las sesiones. Un sistema que proporcione una referencia visual del cuerpo humano y retroalimentación clara ayudaría a que el paciente entienda su progreso y sea más constante en sus ejercicios domiciliarios.

### VII. Reformulación del problema

i. Problemática Clínica

Ante la alta prevalencia de dolor de hombro y el abandono terapéutico, la evaluación subjetiva impide detectar compensaciones y riesgos fisiológicos en tiempo real. Se requiere un sistema portátil y económico que mejore la fatiga y calidad del movimiento para una rehabilitación hospitalaria segura.

ii. Brecha tecnológica

Corresponde a la ausencia de dispositivos portátiles de bajo costo que integren simultáneamente el monitoreo cinemático y fisiológico (ECG/Presión arterial), superando a equipos clínicos fijos de difícil acceso para la mayoría de la población por diversos factores.

VIII. Bibliografía : en formato IEEE.

[1] D. Beard, D. Hamilton, L. Davies, J. Cook, A. Hirst, P. McCulloch, and A. Paez, "Evidence-Based Evaluation of Practice and Innovation in Physical Therapy Using the IDEAL-Physio Framework," Phys. Ther., vol. 98, no. 2, pp. 108–121, Feb. 2018. doi: 10.1093/ptj/pzx103
[2] T. Braun, A. Rieckmann, F. Weber, and C. Grüneberg, "Current use of measurement instruments by physiotherapists working in Germany: a cross-sectional online survey," BMC Health Serv. Res., vol. 18, art. no. 810, Oct. 2018. doi: 10.1186/s12913-018-3563-2
[3] “Trastornos musculoesqueléticos”. World Health Organization (WHO). Accedido el 2
de | abril | de | 2026. | [En | línea]. | Disponible:
https://www.who.int/es/news-room/fact-sheets/detail/musculoskeletal-conditions
[4] Sumed XXI, “Trastornos muscuesqueléticos comunes: Cómo identificarlos y tratarlos -
Sumed | XXI,” | Sumed | XXI, | Oct. | 14, | 2024.
https://sumed.es/es/blog/trastornos-muscuesqueleticos-comunes-como-identificarlos-y-tr atarlos-b62.html (https://sumed.es/es/blog/trastornos-muscuesqueleticos-comunes-como-identificarlos-y-tratarlos-b62.html)

[5] K. Walker-Bone y K. T Palmer. “Prevalence and impact of musculoskeletal disorders of the upper limb in the general population - PubMed”. PubMed. Accedido el 2 de abril de 2026. [En línea]. Disponible: https://pubmed.ncbi.nlm.nih.gov/15334439/
[6] B. M. Huisstede, S. M. Bierma-Zeinstra, B. W. Koes, and J. A. Verhaar, “Incidence and prevalence of upper-extremity musculoskeletal disorders. A systematic appraisal of the literature,” BMC Musculoskeletal Disorders, vol. 7, no. 1, p. 7, Jan. 2006, doi: 10.1186/1471-2474-7-7.
[7] L. JJ y K. B W. “Prevalencia e incidencia del dolor de hombro en la población general; Una revisión sistemática”. PubMed. Accedido el 2 de abril de 2026. [En línea]. Disponible: https://pubmed.ncbi.nlm.nih.gov/15163107/
[8] J. I. Brox. “Dolor en el hombro”. ScienceDirect. Accedido el 2 de abril de 2026. [En línea]. Disponible: https://doi.org/10.1016/S1521-6942(02)00101-8
[9] OMS. “Rehabilitación”. World Health Organization (WHO). Accedido el 2 de abril de
2026. | | | [En | | | | línea]. | | | Disponible:
https://www.who.int/es/news-room/fact-sheets/detail/rehabilitation
[10] A. Guevara Tirado y J. Sanchez Gavidia, “Grado de dolor, trastornos musculoesqueléticos más frecuentes y características sociodemográficas de pacientes atendidos en el Área de Terapia Física y Rehabilitación de un centro médico de Villa El Salvador, Lima, Perú”, Horiz. Medico (Lima), vol. 22, n.º 3, septiembre de 2022, art. n.º
e1959. | Accedido | el | 2 | de | abril | de | 2026. | [En | línea]. | Disponible:
https://doi.org/10.24265/horizmed.2022.v22n3.04
[11] A. B. Reisman. “El Perú tiene apenas 42 médicos especialistas por cada 100 mil
habitantes”. | El | Comercio. | [En | línea]. | Disponible:
https://elcomercio.pe/ecdata/el-peru-tiene-apenas-42-medicos-especialistas-por-cada-100-mil-habitantes-minsa-regiones-ecdata-noticia/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 (https://elcomercio.pe/ecdata/el-peru-tiene-apenas-42-medicos-especialistas-por-cada-100-mil-habitantes-minsa-regiones-ecdata-noticia/)
[12] “Crece demanda de terapistas físicos por problemas de salud ocupacional”. Agencia
Peruana de Noticias | ANDINA. Accedido el 2 de abril de 2026. [En línea]. Disponible:
https://andina.pe/agencia/noticia-crece-demanda-terapistas-fisicos-problemas-salud-ocu pacional-734878.aspx (https://andina.pe/agencia/noticia-crece-demanda-terapistas-fisicos-problemas-salud-ocupacional-734878.aspx)
[13] C. B. Murray, R. de la Vega, L. K. Murphy, S. Kashikar-Zuck, and T. M. Palermo, "The prevalence of chronic pain in young adults: a systematic review and meta-analysis," PAIN, vol. 163, no. 9, pp. e972–e984, Sep. 2022. doi: 10.1097/j.pain.0000000000002541
[14] R. De Fazio, V. M. Mastronardi, M. De Vittorio, and P. Visconti, "Wearable Sensors and Smart Devices to Monitor Rehabilitation Parameters and Sports Performance: An Overview," Sensors, vol. 23, no. 4, art. no. 1856, Feb. 2023. doi: 10.3390/s23041856
[15] G. J. Kim, A. Parnandi, S. Eva y H. Schambra, “The use of wearable sensors to assess and treat the upper extremity after stroke: a scoping review,” Disability and Rehabilitation, vol. 44, no. 20, pp. 6119–6138, Oct. 2022, doi: 10.1080/09638288.2021.1957027.

[16] N. Ramírez Suárez, Propuesta de juego serio enfocado a la rehabilitación muscular de miembro superior, propuesta de investigación de maestría, Maestría en Ingeniería Mecatrónica, Facultad de Ingeniería, Universidad Militar Nueva Granada, Bogotá, Colombia, 2024.
[17] S. Zhao, J. Liu, Z. Gong, Y. Lei, X. OuYang, C. C. Chan y S. Ruan, “Wearable physiological monitoring system based on electrocardiography and electromyography for upper limb rehabilitation training,” Sensors, vol. 20, no. 17, p. 4861, 2020, doi: 10.3390/s20174861.
[18] A. Maeda, F. Fujita, H. Kanatani, S. Ikegawa, and H. Kubo, “Dispositivo de asistencia de rehabilitación y programa para controlar el dispositivo de asistencia de rehabilitación,” ES Patent 2 693 095 T3, Dec. 7, 2018.
[19] A. Maeda, F. Fujita, H. Kanatani, S. Ikegawa, and H. Kubo, “Dispositivo de asistencia de rehabilitación y programa para controlar el dispositivo de asistencia de rehabilitación,” ES Patent 2 693 095 T3, assigned to Teijin Pharma Limited, Dec. 7, 2018.

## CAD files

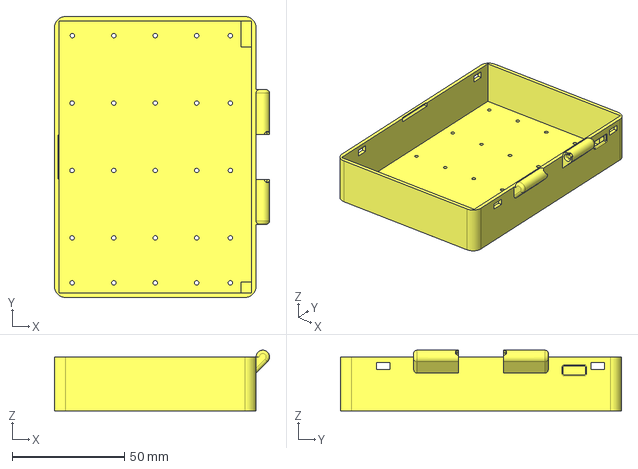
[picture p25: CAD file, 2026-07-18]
Modelado 3D/Brazo_base_final.step
95.7 x 125.0 x 27.0 mm

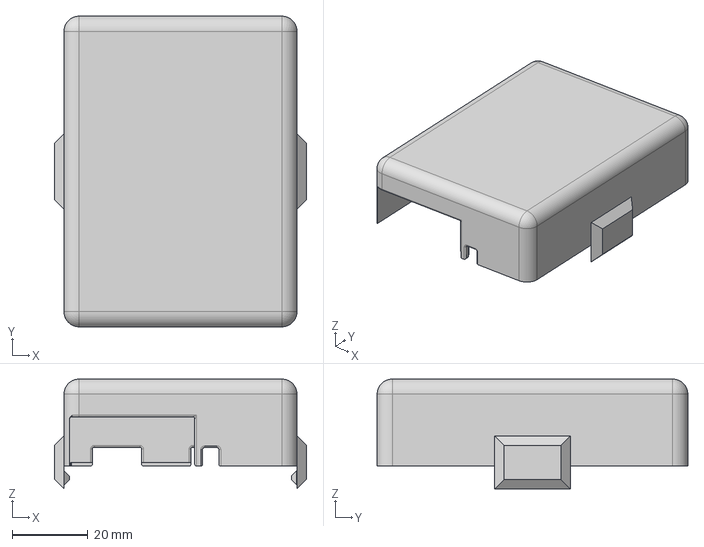
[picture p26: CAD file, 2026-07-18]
Modelado 3D/tapa_pecho.step
66.5 x 82.0 x 29.0 mm

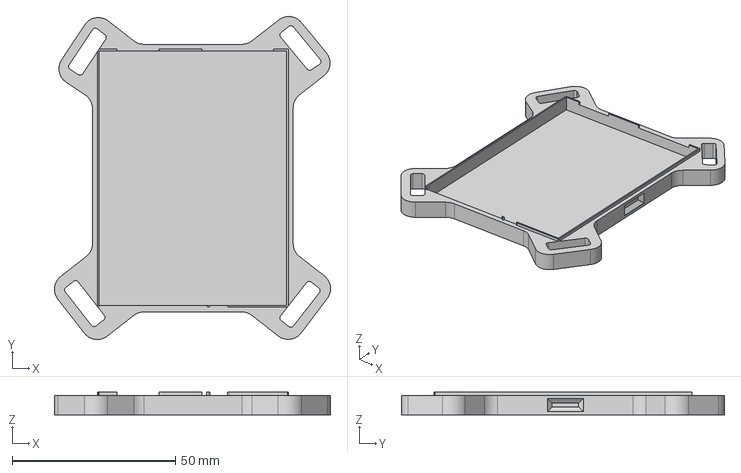
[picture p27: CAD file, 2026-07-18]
Modelado 3D/base_pecho.step
84.6 x 99.0 x 7.00 mm

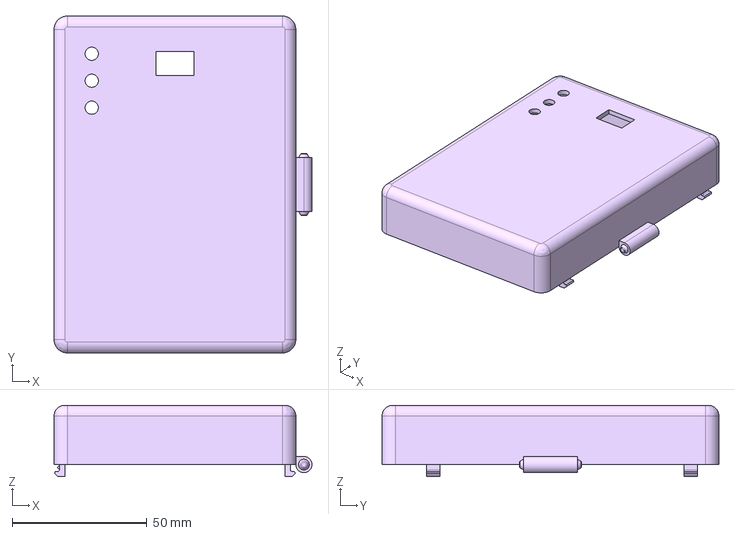
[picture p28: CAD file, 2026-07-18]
Modelado 3D/Brazo_tapa_final.step
95.7 x 125.0 x 26.5 mm
